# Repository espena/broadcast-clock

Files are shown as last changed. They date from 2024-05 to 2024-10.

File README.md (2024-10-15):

# Broadcast clock

**Digital precision studio/broadcast master clock with WiFi configuration, NTP client/server and GPS time sync.**

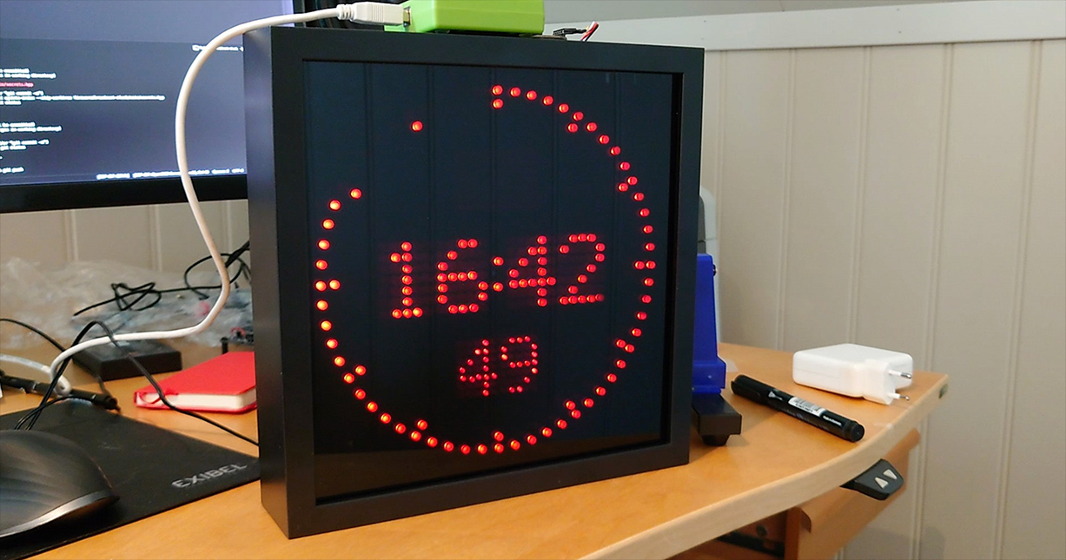
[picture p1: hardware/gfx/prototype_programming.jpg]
Home made broadcast clock Broadcast studio clock


## Details

You'll find a complete project description on [my personal home page](https://espenandersen.no/esp32-broadcast-clock/ "Broadcast clock with ESP32 and NTP/GPS time receiver").

The enclosure is an 25x25 cm [IKEA "Sannahed"](https://www.ikea.com/us/en/p/sannahed-frame-black-60459118/) photo frame, which is deep enough to encapsulate the circuitry. I replaced the provided plexi glass with a dark acrylic glass plate.

There are no traditional buttons to control the clock. Instead, it has a browser based web configurator. When powered on, the clock will expose a dedicated wifi network for 30 seconds. Connect to the network in order to access the clock's control panel.

The clock supports time synchronization over the web (NTP) or via a range of GNSS satellite systems (GPS/QZSS, GLONASS, BeiDou, Galileo). It acts as a highly accurate NTP time server for other clocks on your LAN.

LED brightness is auto-adjusted to ambient light conditions. This feature can be overridden in the control panel.

It also has a stopwatch and a countdown timer that is operated from the browser interface.

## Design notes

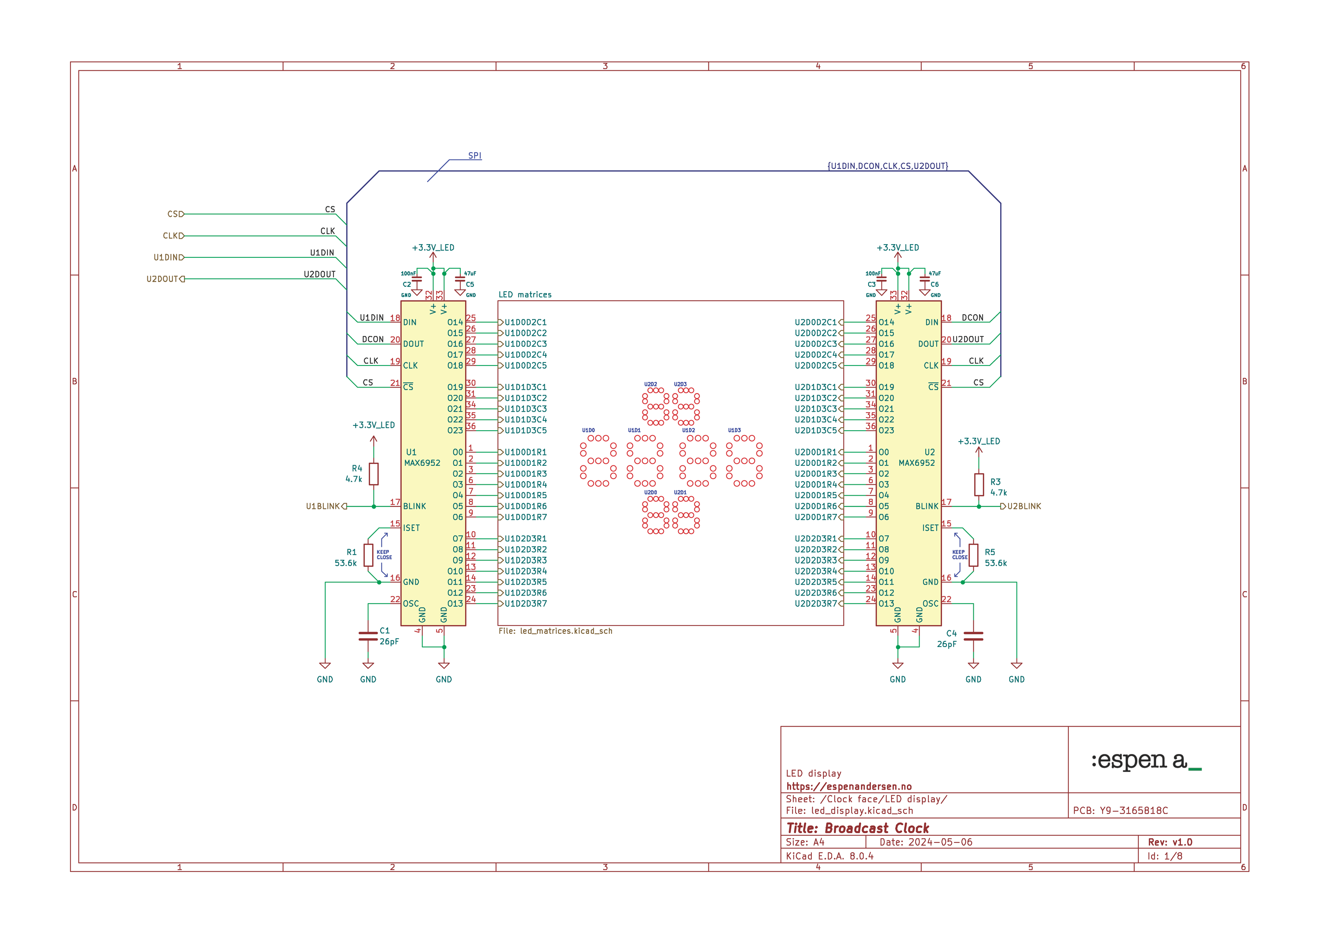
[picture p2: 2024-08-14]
drawings/schematics_png/schematics_Page_6.png

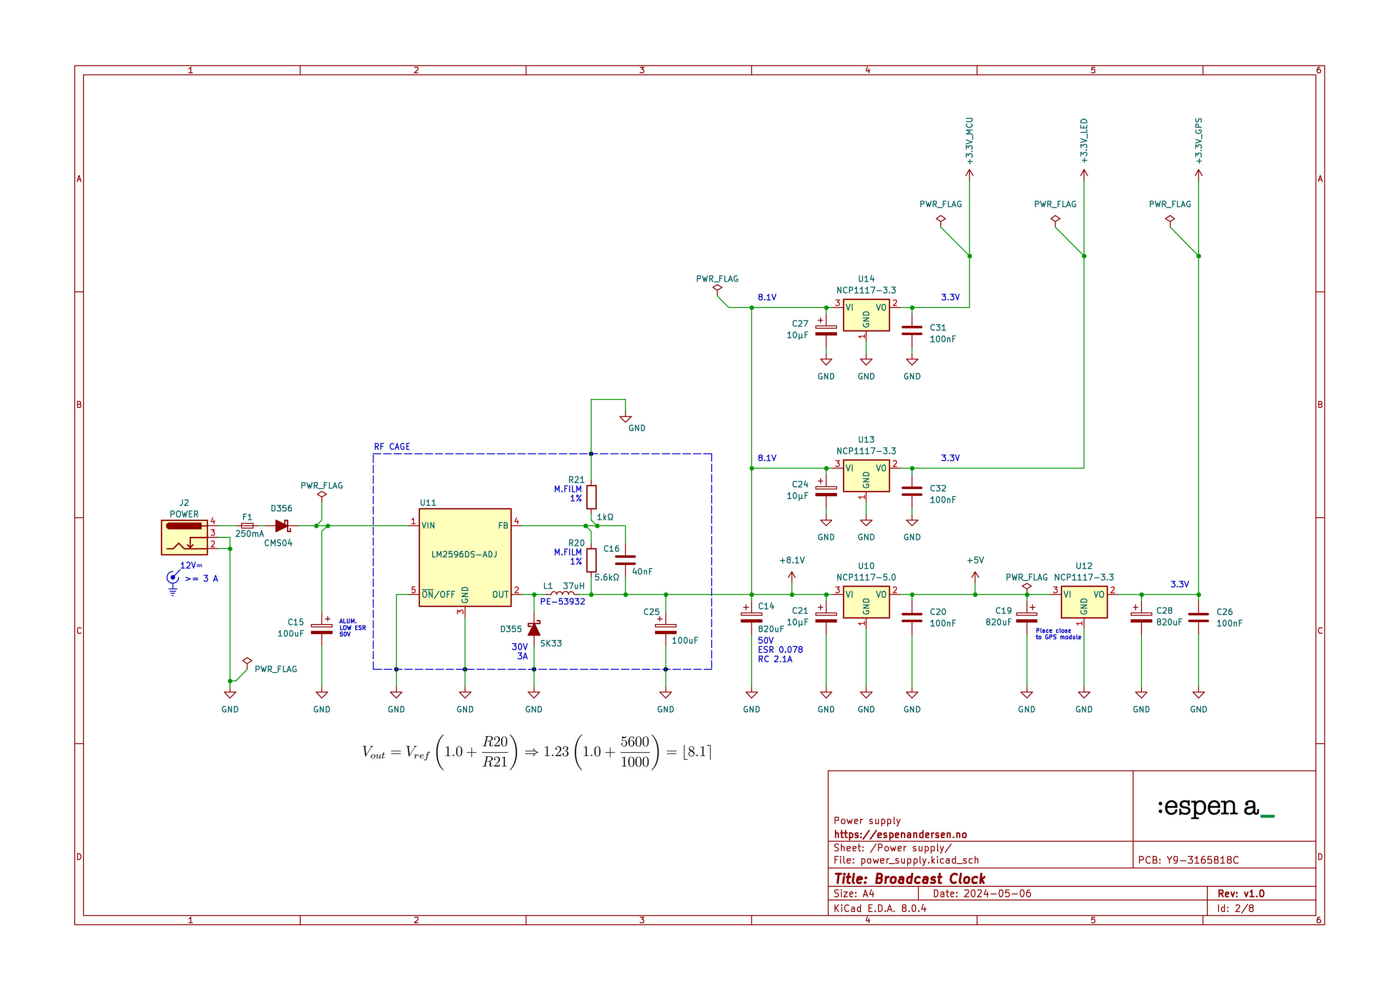
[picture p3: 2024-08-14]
drawings/schematics_png/schematics_Page_2.png

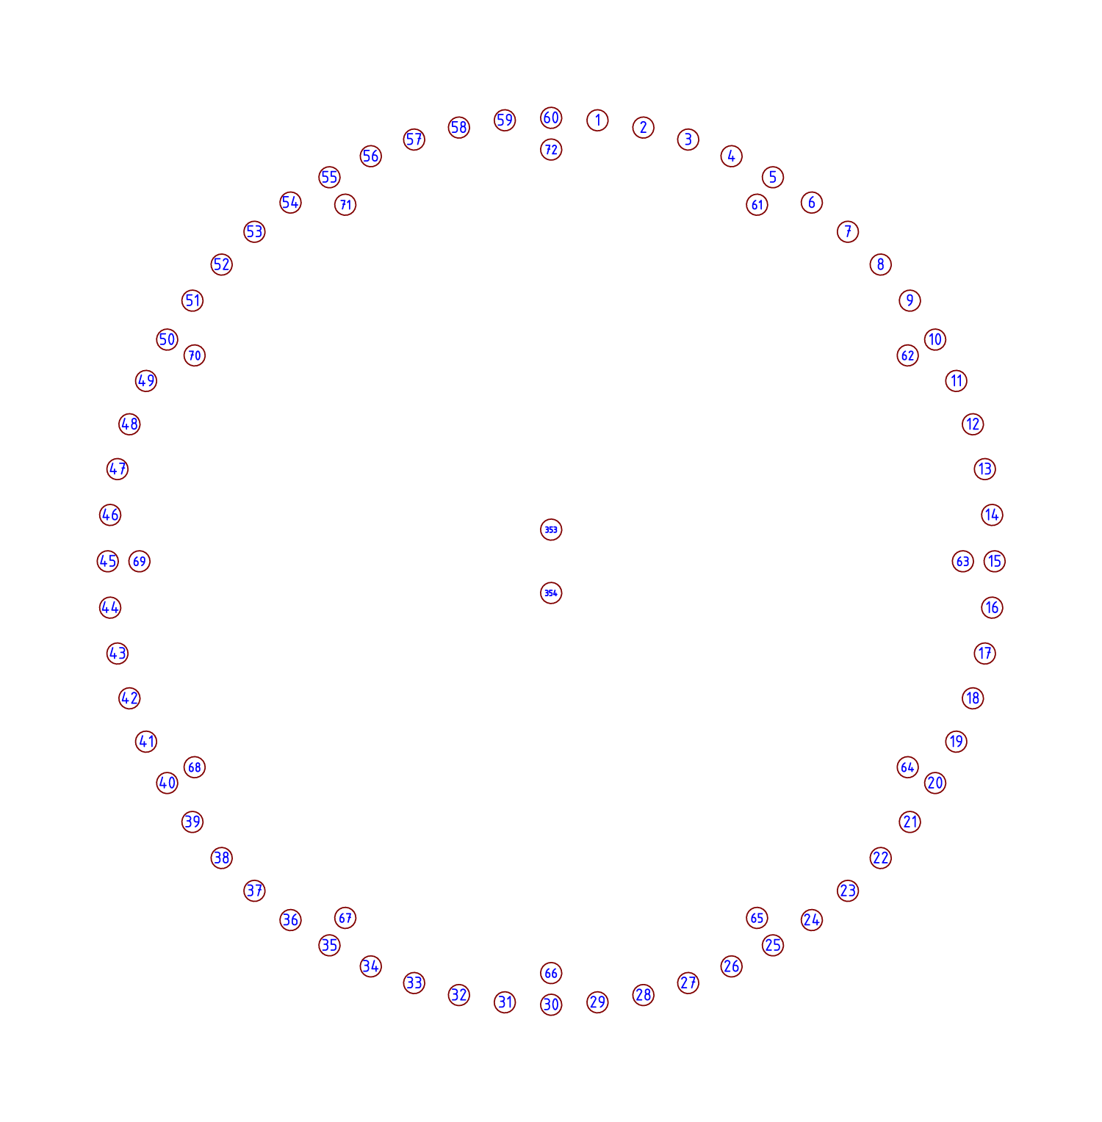
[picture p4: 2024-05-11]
hardware/gfx/dial.png

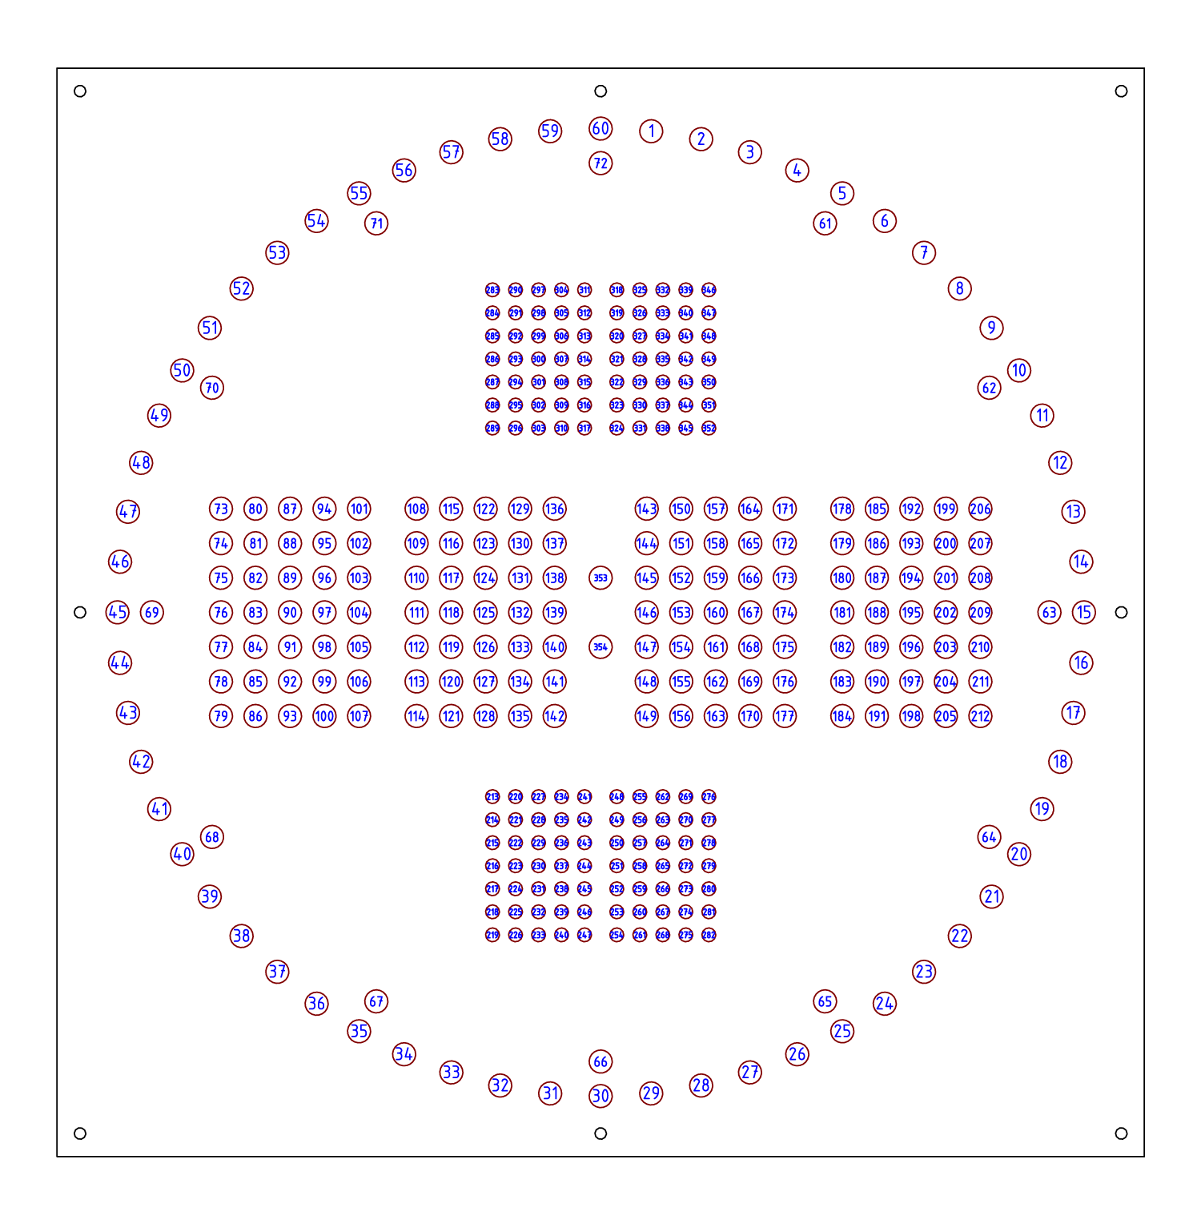
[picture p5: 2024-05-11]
hardware/gfx/face.png

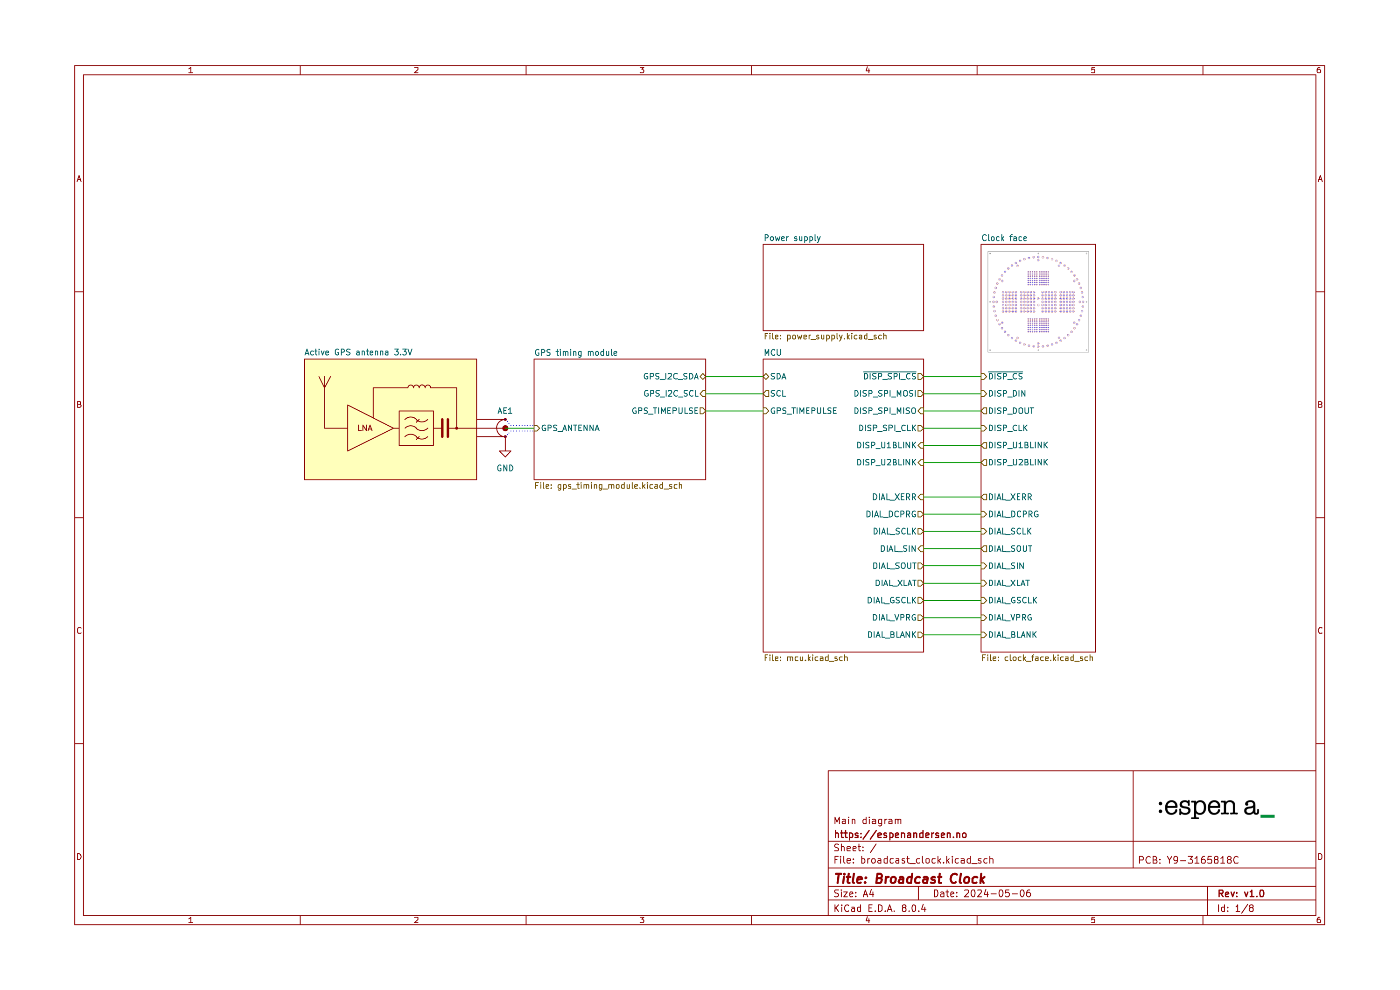
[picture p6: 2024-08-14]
drawings/schematics_png/schematics_Page_1.png

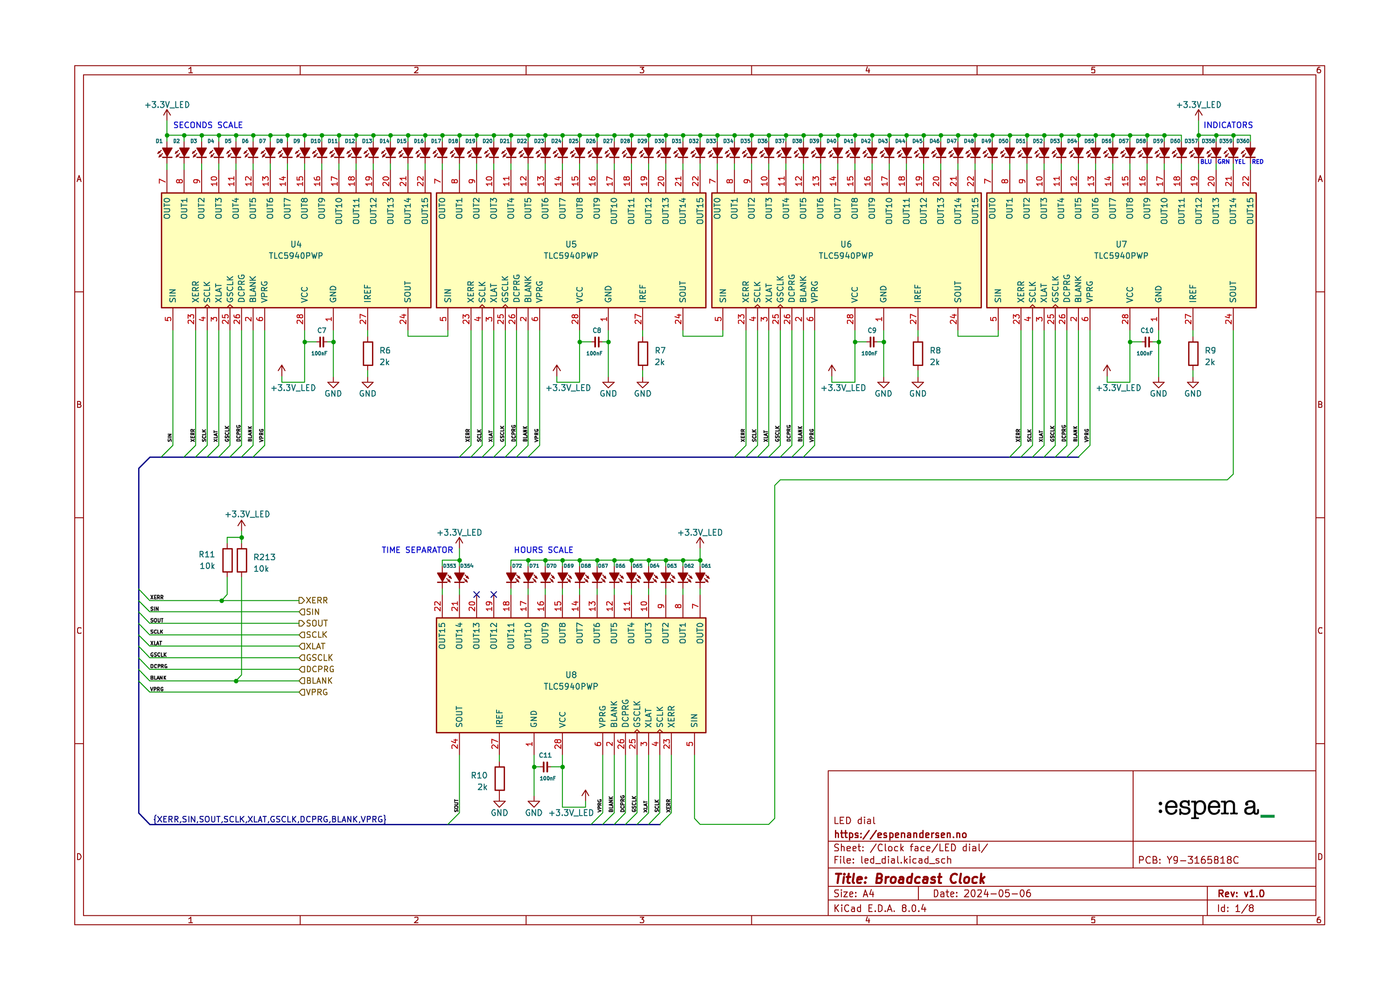
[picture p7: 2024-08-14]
drawings/schematics_png/schematics_Page_8.png

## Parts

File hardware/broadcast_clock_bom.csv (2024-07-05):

Reference | Value | Datasheet | Footprint | Qty | DNP
AE1 | Active GPS antenna 3.3V | ~ | Connector_Coaxial:SMA_Amphenol_132291-12_Vertical | 1
BT1 | CR 2032 | ~ | Battery:BatteryHolder_Keystone_1058_1x2032 | 1
BZ1 | Buzzer | ~ | Transducer_espena:TP094003_Transducer_9x9mm | 1
C1,C4 | 26pF | ~ | Capacitor_SMD:C_0805_2012Metric | 2
C2,C3,C7,C8,C9,C10,C11,C20,C22,C26,C31,C32 | 100nF | ~ | Capacitor_SMD:C_0805_2012Metric | 12
C5,C6,C13 | 47uF | ~ | Capacitor_SMD:C_0805_2012Metric | 3
C12 | 1uF | ~ | Capacitor_SMD:C_0805_2012Metric | 1
C14,C19,C28 | 820uF | ~ | Capacitor_SMD_espena:CP_Elec_18x16.5 | 3
C15,C25 | 100uF | ~ | Capacitor_SMD:CP_Elec_8x10 | 2
C16 | 40nF | ~ | Capacitor_SMD:C_0805_2012Metric | 1
C17 | 10nF | ~ | Capacitor_SMD:C_0805_2012Metric | 1
C18 | 47pF | ~ | Capacitor_SMD:C_0805_2012Metric | 1
C21,C24,C27 | 10µF | ~ | Capacitor_SMD:C_0805_2012Metric | 3
C23 | 10μF | ~ | Capacitor_SMD:C_0805_2012Metric | 1
D1,D2,D3,D4,D5,D6,D7,D8,D9,D10,D11,D12,D13,D14,D15,D16,D17,D18,D19,D20,D21,D22,D23,D24,D25,D26,D27,D28,D29,D30,D31,D32,D33,D34,D35,D36,D37,D38,D39,D40,D41,D42,D43,D44,D45,D46,D47,D48,D49,D50,D51,D52,D53,D54,D55,D56,D57,D58,D59,D60,D61,D62,D63,D64,D65,D66,D67,D68,D69,D70,D71,D72,D73,D74,D75,D76,D77,D78,D79,D80,D81,D82,D83,D84,D85,D86,D87,D88,D89,D90,D91,D92,D93,D94,D95,D96,D97,D98,D99,D100,D101,D102,D103,D104,D105,D106,D107,D108,D109,D110,D111,D112,D113,D114,D115,D116,D117,D118,D119,D120,D121,D122,D123,D124,D125,D126,D127,D128,D129,D130,D131,D132,D133,D134,D135,D136,D137,D138,D139,D140,D141,D142,D143,D144,D145,D146,D147,D148,D149,D150,D151,D152,D153,D154,D155,D156,D157,D158,D159,D160,D161,D162,D163,D164,D165,D166,D167,D168,D169,D170,D171,D172,D173,D174,D175,D176,D177,D178,D179,D180,D181,D182,D183,D184,D185,D186,D187,D188,D189,D190,D191,D192,D193,D194,D195,D196,D197,D198,D199,D200,D201,D202,D203,D204,D205,D206,D207,D208,D209,D210,D211,D212,D213,D214,D215,D216,D217,D218,D219,D220,D221,D222,D223,D224,D225,D226,D227,D228,D229,D230,D231,D232,D233,D234,D235,D236,D237,D238,D239,D240,D241,D242,D243,D244,D245,D246,D247,D248,D249,D250,D251,D252,D253,D254,D255,D256,D257,D258,D259,D260,D261,D262,D263,D264,D265,D266,D267,D268,D269,D270,D271,D272,D273,D274,D275,D276,D277,D278,D279,D280,D281,D282,D283,D284,D285,D286,D287,D288,D289,D290,D291,D292,D293,D294,D295,D296,D297,D298,D299,D300,D301,D302,D303,D304,D305,D306,D307,D308,D309,D310,D311,D312,D313,D314,D315,D316,D317,D318,D319,D320,D321,D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 | 620nm | ~ | -- mixed values -- | 355
D355 | SK33 | ~ | Diode_SMD:D_SMA | 1
D356 | CMS04 | ~ | Diode_SMD_mouser:SODFL4724X108N | 1
D357 | 470nm | ~ | LED_SMD:LED_0805_2012Metric | 1
D358 | 570nm | ~ | LED_SMD:LED_0805_2012Metric | 1
D359 | 590nm | ~ | LED_SMD:LED_0805_2012Metric | 1
F1 | 2A | ~ | Fuse_espena:FuseHolder_Keystone_3554 | 1
J1 | UART MCU | ~ | Connector_espena:Magnetic-Pogo-Female-MG0425FB_1x4_P2.54mm | 1
J2 | POWER | ~ | Connector_BarrelJack_espena:BarrelJack_DC044_Horizontal | 1
J3 | UART GPS | ~ | Connector_PinHeader_1.27mm:PinHeader_1x06_P1.27mm_Vertical | 1
L1 | 37uH | ~ | Inductor_SMD_espena:L_Pulse_LCI-44 | 1
L2 | 27nH | ~ | Inductor_SMD_espena:L_Coilcraft_0805CS | 1
R1,R5 | 53.6k | ~ | Resistor_SMD:R_0805_2012Metric | 2
R2,R3,R13 | 4.7k | ~ | Resistor_SMD:R_0805_2012Metric | 3
R4,R11 | R | ~ | Resistor_SMD:R_0805_2012Metric | 2
R6,R7,R8,R9,R10 | 2k | ~ | Resistor_SMD:R_0805_2012Metric | 5
R12 | 4,7k | ~ | Resistor_SMD:R_0805_2012Metric | 1
R14,R16,R22,R213 | 10k | ~ | Resistor_SMD:R_0805_2012Metric | 4
R15 | 10k | ~ | Resistor_SMD:R_0805_2012Metric | 1 | DNP
R17,R18 | 4k7 | ~ | Resistor_SMD:R_0805_2012Metric | 2 | DNP
R19 | 4k7 | ~ | Resistor_SMD:R_0805_2012Metric | 1
R20 | 5.6kΩ | ~ | Resistor_SMD:R_0805_2012Metric | 1
R21 | 1kΩ | ~ | Resistor_SMD:R_0805_2012Metric | 1
R24 | 10Ω | ~ | Resistor_SMD:R_0805_2012Metric | 1
SW1 | BOOT | ~ | Button_Switch_SMD_espena:SW_SPST_TL3301_6x6mm_H4.3mm | 1
SW2 | RESET | ~ | Button_Switch_SMD_espena:SW_SPST_TL3301_6x6mm_H4.3mm | 1
U1,U2 | MAX6952 | https://www.analog.com/MAX6952/datasheet | Package_SO_espena:SSOP-36_7.5x12.5mm_P0.65mm | 2
U3 | ESP32-WROVER-E | https://www.espressif.com/sites/default/files/documentation/esp32-wrover-b_datasheet_en.pdf | RF_Module_espena:ESP32-WROVER-B | 1
U4,U5,U6,U7,U8 | TLC5940PWP | http://www.ti.com/lit/ds/symlink/tlc5940.pdf | Package_SO:HTSSOP-28-1EP_4.4x9.7mm_P0.65mm_EP3.4x9.5mm_Mask2.4x6.17mm_ThermalVias | 5
U9 | LEA-M8T | https://content.u-blox.com/sites/default/files/documents/NEO-LEA-M8T-FW3_DataSheet_UBX-15025193.pdf | RF_GPS_espena:ublox_LEA | 1
U10 | NCP1117-5.0 | http://www.onsemi.com/pub_link/Collateral/NCP1117-D.PDF | Package_TO_SOT_SMD:SOT-223-3_TabPin2 | 1
U11 | LM2596DS-ADJ | http://www.ti.com/lit/ds/symlink/lm2596.pdf | Regulator_SMD_mouser:NCP5663DSADJR4G | 1
U12,U13,U14 | NCP1117-3.3 | http://www.onsemi.com/pub_link/Collateral/NCP1117-D.PDF | Package_TO_SOT_SMD:SOT-223-3_TabPin2 | 3
U15 | VEML7700 | https://www.vishay.com/docs/84286/veml7700.pdf | Sensor_espena:VEML7700 | 1

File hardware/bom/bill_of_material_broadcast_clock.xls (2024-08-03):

BROADCAST CLOCK
Mouser No | Mfr. No | Manufacturer | Description | RoHS | Order Qty. | Price (NOK) | Ext.: (NOK)
700-MAX6952EAX | MAX6952EAX+ | Analog Devices Inc. | LED Display Drivers 4-Wire Interfaced, 2.7V to 5.5V, 4-Digit | RoHS Compliant | 2 | kr 399.98 | kr 799.96
595-TLC5940PWPR | TLC5940PWPR | Texas Instruments | LED Lighting Drivers 4096 Step Grayscale LED Driver | RoHS Compliant | 5 | kr 33.26 | kr 166.30
863-LM2596DSADJR4G | LM2596DSADJR4G | onsemi | Switching Voltage Regulators 3A BUCK SWCH 150KHZ | RoHS Compliant By Exemption | 1 | kr 28.99 | kr 28.99
833-SK33A-LTP | SK33A-LTP | Micro Commercial Components (MCC) | Schottky Diodes & Rectifiers DIODE SCHOTTKY 30V 3A DO214AC | RoHS Compliant By Exemption | 1 | kr 4.62 | kr 4.62
673-PE-53932SNLT | PE-53932SNLT | Pulse | Common Mode Chokes / Filters SMT COMMON MODE INDUCTOR | RoHS Compliant | 1 | kr 33.15 | kr 33.15
647-UCZ1H821MNS1MS | UCZ1H821MNS1MS | Nichicon | Aluminium Electrolytic Capacitors - SMD 50V 820uf 20% SMD, high vibration | RoHS Compliant | 3 | kr 33.84 | kr 101.52
647-UWT1H101MNL1S | UWT1H101MNL1GS | Nichicon | Aluminium Electrolytic Capacitors - SMD 50volts 100uF AEC-Q200 | RoHS Compliant | 1 | kr 5.15 | kr 5.15
757-CMS04TE12L,Q,M | CMS04(TE12L,Q,M) | Toshiba | Schottky Diodes & Rectifiers Diode Schottky 30V 5A | RoHS Compliant | 1 | kr 9.24 | kr 9.24
377-LEA-M8T-1 | LEA-M8T-1 | u-blox | GNSS / GPS Modules u-blox M8 GNSS module Timing LCC, 17x22.4mm, 250 pcs/reel | RoHS Compliant | 1 | kr 1031.18 | kr 1031.18
530-MRT250AMMO | MRT250AMMO | Bel | Fuses with Leads - Through Hole 250mA 250V | RoHS Compliant | 1 | kr 4.84 | kr 4.84
652-CR0805FX-5601ELF | CR0805-FX-5601ELF | Bourns | Thick Film Resistors - SMD 5.6K 1% | RoHS Compliant By Exemption | 1 | kr 1.07 | kr 1.07
652-CR0805FX-1001ELF | CR0805-FX-1001ELF | Bourns | Thick Film Resistors - SMD 1K 1% | RoHS Compliant By Exemption | 1 | kr 1.07 | kr 1.07
80-C0805C393F5J | C0805C393F5JACTU | KEMET | Multilayer Ceramic Capacitors MLCC - SMD/SMT 50V .039uF U2J 0805 1% | RoHS Compliant | 1 | kr 13.40 | kr 13.40
80-C0805X106J8RAUTO | C0805X106J8RACAUTO | KEMET | Multilayer Ceramic Capacitors MLCC - SMD/SMT 10 Vo 10 uF 0805 X7R 5 % AECQ200 | RoHS Compliant | 4 | kr 10.31 | kr 41.24
80-C0805C104K8RAUTO | C0805C104K8RACAUTO | KEMET | Multilayer Ceramic Capacitors MLCC - SMD/SMT 10Vo 0.1uF X7R 0805 10% AEC-Q200 | RoHS Compliant | 12 | kr 0.87 | kr 10.39
863-NCP1117IST50T3G | NCP1117IST50T3G | onsemi | LDO Voltage Regulators LDO Regulator, 1 A, Fixed and Adjustable, Positive Vout: 5.0 V | RoHS Compliant | 1 | kr 6.44 | kr 6.44
863-NCP1117ST33T3G | NCP1117ST33T3G | onsemi | LDO Voltage Regulators 3.3V 1A Positive | RoHS Compliant | 3 | kr 7.30 | kr 21.90
78-VEML7700-TR | VEML7700-TR | Vishay | Ambient Light Sensors Opr 2.5-3.6V 0.005lx Side View 16bit I2C | RoHS Compliant | 1 | kr 18.83 | kr 18.83
652-CR0805FX-10R0ELF | CR0805-FX-10R0ELF | Bourns | Thick Film Resistors - SMD 10ohm 1% | RoHS Compliant By Exemption | 2 | kr 1.07 | kr 2.14
179-TS046685BK260SMT | TS04-66-85-BK-260-SMT | CUI Devices | Tactile Switches 6 x 6 mm, 8.5 mm Act Height, 260 gf, Black, Surface Mount, SPST, | RoHS Compliant | 2 | kr 1.93 | kr 3.86
652-CR0805FX-1002ELF | CR0805-FX-1002ELF | Bourns | Thick Film Resistors - SMD 10K 1% | RoHS Compliant By Exemption | 6 | kr 1.07 | kr 6.42
652-CR0805-JW-472ELF | CR0805-JW-472ELF | Bourns | Thick Film Resistors - SMD 4.7KOHM 1/8WATT 5% | RoHS Compliant By Exemption | 4 | kr 1.07 | kr 4.28
187-CL21X476MRYNNWE | CL21X476MRYNNWE | Samsung Electro-Mechanics | Multilayer Ceramic Capacitors MLCC - SMD/SMT 47uF X6S +/-20% 4v 0 0805 | RoHS Compliant | 3 | kr 3.12 | kr 9.36
187-CL21B105KOFNNNE | CL21B105KOFNNNE | Samsung Electro-Mechanics | Multilayer Ceramic Capacitors MLCC - SMD/SMT SAMSUNG | RoHS Compliant | 1 | kr 1.07 | kr 1.07
497-TP094003-1 | TP094003-1 | DB Unlimited | Speakers & Transducers Piezo Transducer | RoHS Compliant | 1 | kr 7.30 | kr 7.30
855-M50-3530642 | M50-3530642 | Harwin | Headers & Wire Housings 6 WAY SIL VERT PC TAIL P/HDR | RoHS Compliant | 1 | kr 3.12 | kr 3.12
534-1058 | 1058 | Keystone Electronics | Coin Cell Battery Holders 2032 COIN CELL HLDER SMT 1.118" | RoHS Compliant | 1 | kr 13.17 | kr 13.17
581-08052U470FAT2A | 08052U470FAT2A | KYOCERA AVX | Multilayer Ceramic Capacitors MLCC - SMD/SMT KGQ21HCG2D470FT NEW GLOBAL PN 200V 47pF A 581-KGQ21HCG2D470FT | RoHS Compliant | 1 | kr 5.05 | kr 5.05
581-0805YA103FAT2A | 0805YA103FAT2A | KYOCERA AVX | Multilayer Ceramic Capacitors MLCC - SMD/SMT KGM21ACG1C103FU NEW GLOBAL PN 16V 0.01uF A 581-KGM21ACG1C103FU | RoHS Compliant | 1 | kr 10.21 | kr 10.21
652-CR0805FX-5362ELF | CR0805-FX-5362ELF | Bourns | Thick Film Resistors - SMD 53.6K 1% | RoHS Compliant By Exemption | 2 | kr 1.07 | kr 2.14
77-VJ0805A270FXXPBC | VJ0805A270FXXPW1BC | Vishay | Multilayer Ceramic Capacitors MLCC - SMD/SMT 0805 27pF 25volts C0G 1% | RoHS Compliant | 2 | kr 3.55 | kr 7.10
859-LTL-307E | LTL-307E | Lite-On | Standard LEDs - Through Hole Red Diffused | RoHS Compliant | 214 | kr 0.94 | kr 200.30
859-LTL-1CHE | LTL-1CHE | Lite-On | Standard LEDs - Through Hole Red Diffused | RoHS Compliant | 140 | kr 0.85 | kr 119.70
652-CR0805FX-1003ELF | CR0805-FX-1003ELF | Bourns | Thick Film Resistors - SMD 100K 1% | RoHS Compliant By Exemption | 1 | kr 1.07 | kr 1.07
652-CR0805FX-2001ELF | CR0805-FX-2001ELF | Bourns | Thick Film Resistors - SMD 2K 1% | RoHS Compliant By Exemption | 5 | kr 1.07 | kr 5.35
710-150080YS75000 | 150080YS75000 | Wurth Elektronik | Standard LEDs - SMD WL-SMCW SMDMono TpVw Waterclr 0805 Yellow | RoHS Compliant | 1 | kr 2.04 | kr 2.04
710-150080VS75000 | 150080VS75000 | Wurth Elektronik | Standard LEDs - SMD WL-SMCW SMDMono TpVw Waterclr 0805 BrtGrn | RoHS Compliant | 1 | kr 2.04 | kr 2.04
710-150080RS75000 | 150080RS75000 | Wurth Elektronik | Standard LEDs - SMD WL-SMCW SMDMono TpVw Waterclr 0805 Red | RoHS Compliant | 1 | kr 2.04 | kr 2.04
710-150080BS75000 | 150080BS75000 | Wurth Elektronik | Standard LEDs - SMD WL-SMCW SMDMono TpVw Waterclr 0805 Blue | RoHS Compliant | 1 | kr 2.04 | kr 2.04
523-132291-12 | 132291-12 | Amphenol | RF Connectors / Coaxial Connectors STRT BH PC MT JK .105 LEGS | RoHS Compliant By Exemption | 1 | kr 93.79 | kr 93.79
356-ESP32WRVE22864PC | ESP32-WROVER-E-N16R8 | Espressif | Multiprotocol Modules SMD Module ESP32-WROVER-E, ESP32-D0WD-V3, 3.3V 64Mbit PSRAM, 16 MB SPI flash, PCB Antenna | RoHS Compliant | 1 | kr 36.38 | kr 36.38
 |  | DC Barrel plug |  |  | 1 | kr 1.00 | kr 1.00
 |  | Enclosure | IKEA "Sannahed" |  | 1 | kr 69.00 | kr 55.00
 |  | PCB | JLCPCB |  | 1 | kr 440.00 | kr 280.00
 |  | Acrylic front glass |  |  | 1 | kr 150.00 | kr 150.00
 |  | Back plate | Tronrud Engineering |  | 1 | kr 200.00 | kr 200.00
 |  | Munting material | Standoffs, nuts, screws |  |  | kr 50.00 | kr 30.00
 |  | Grand total |  |  |  |  | kr 3555.26

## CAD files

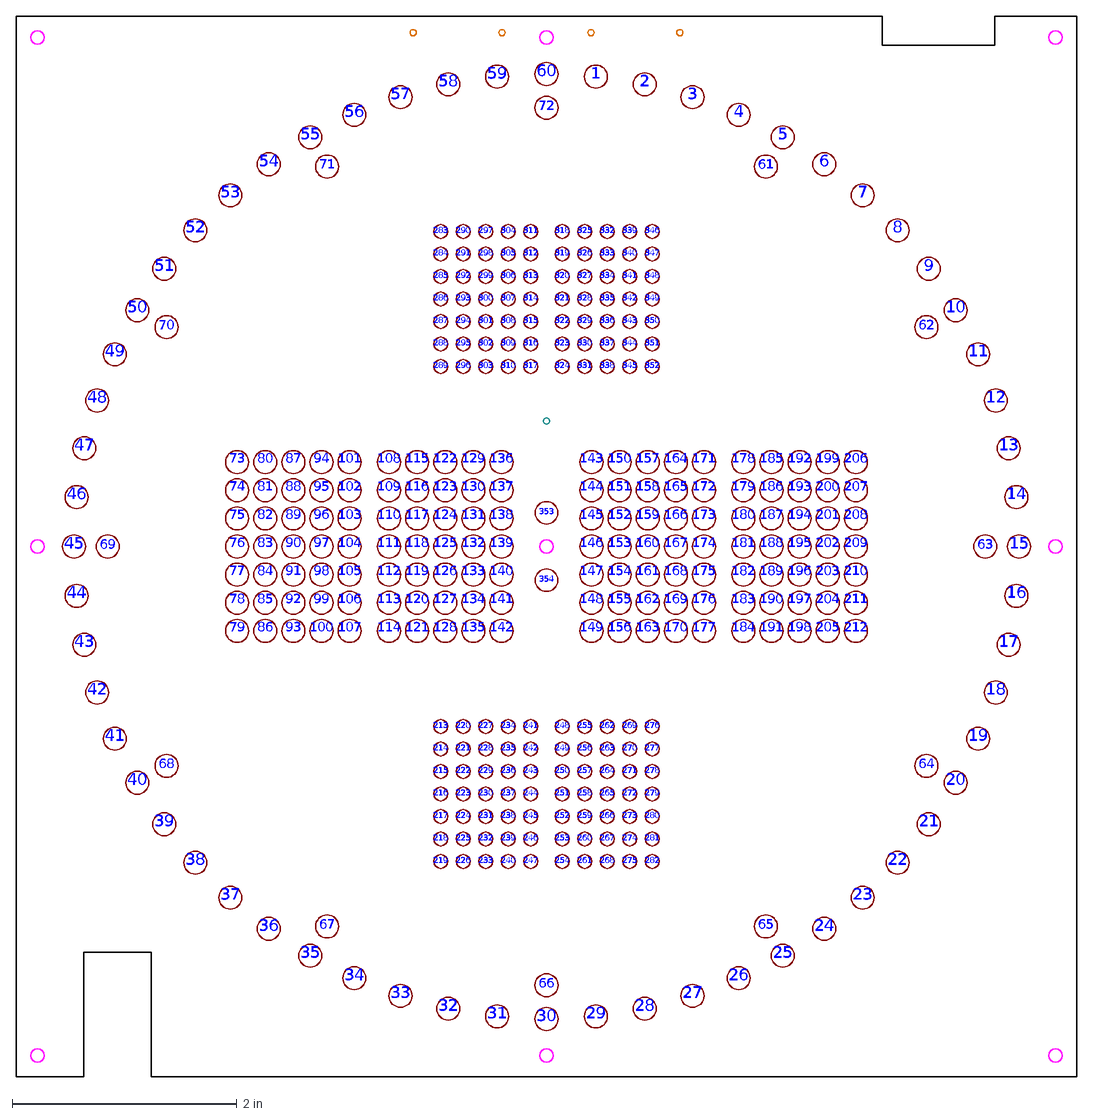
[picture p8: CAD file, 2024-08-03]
drawings/clock_panels.dxf
1
2
3
4
5
6
7
8
9
10
11
12
13
14
15
16
17
18
19
20
21
22
23
24
25
26
27
28
29
30
31
32
33
34
35
36
37
38
39
40
41
42
43
44
45
46
47
48
49
50
51
52
53
54
55
56
57
58
59
60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

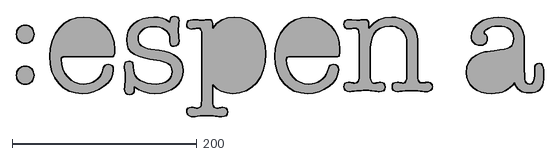
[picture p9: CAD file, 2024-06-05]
hardware/gfx/logo.dxf
571.4 x 108.8

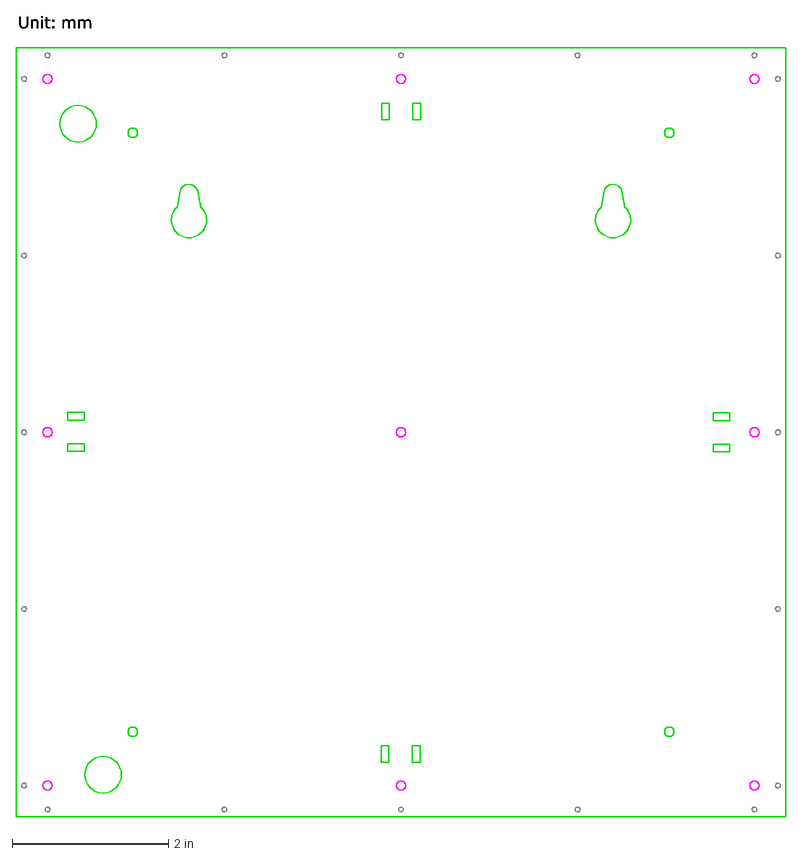
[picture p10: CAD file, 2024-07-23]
drawings/back_plate.dxf
Unit: mm

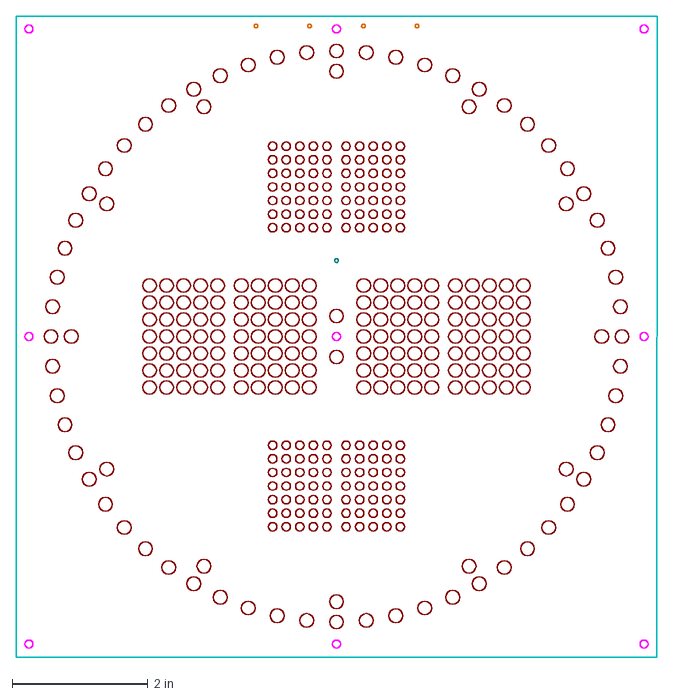
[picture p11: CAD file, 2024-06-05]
drawings/front_panel.dxf
9.43 x 9.43 in

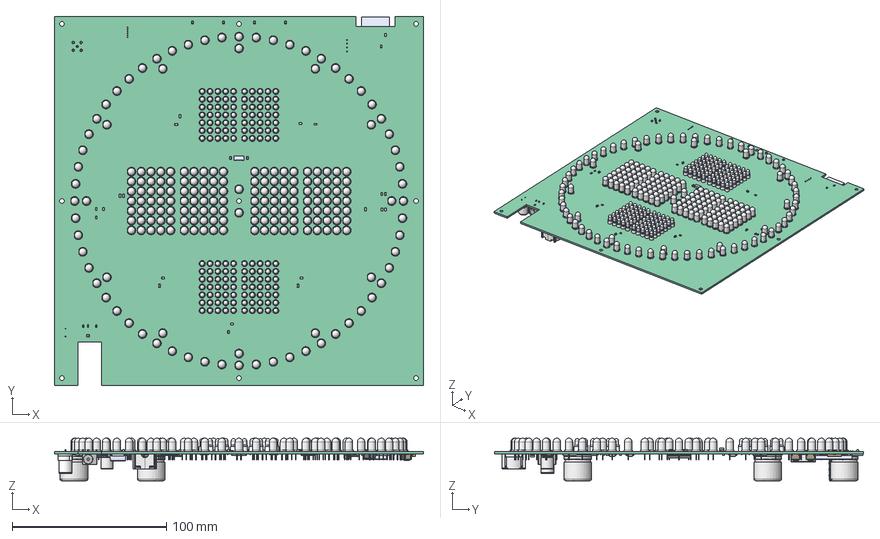
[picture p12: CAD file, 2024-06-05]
drawings/printed_circuit_board.FCStd
239.5 x 239.5 x 27.8 mm
Pcb_7181
${REFERENCE}_LED_D3.0mm_null x 140
${REFERENCE}_Body_null[2] x 140
${REFERENCE}_LED_D5.0mm_null x 214
${REFERENCE}_R_0805_2012Metric_null x 24
${REFERENCE}_C_0805_2012Metric_null x 25
${REFERENCE}_LED_0805_2012Metric_null x 4
${REFERENCE}_VEML7700-TR_null
${REFERENCE}_HTSSOP_28_1EP_44x97mm_P065mm_null x 5
${REFERENCE}_SOT_223_null x 4
${REFERENCE}_Keystone_1058_1x2032_null
${REFERENCE}_CP_Elec_18x175_null x 3
${REFERENCE}_SW_SPST_TL3301_6x6mm_H4.3mm_null x 2
${REFERENCE}_SMA_Amphenol_132291-12_Vertical_null
${REFERENCE}_ESP32-WROVER-B_null
${REFERENCE}_DC044_connector_5.5x2.1mm_null
${REFERENCE}_D_SMA_null
${REFERENCE}_Inductor_Coilcraft_0805CS_null
${REFERENCE}_PinHeader_1x06_P127mm_Vertical_null
${REFERENCE}_Fuse_MXT250_With_Socket_null
${REFERENCE}_Fuse_MXT250_null[2]
${REFERENCE}_PE5393NSL_inductor_null
${REFERENCE}_MAX6952EAX+_null x 2
${REFERENCE}_PogoFemale_null
${REFERENCE}_LM2596DSADJR4G_null
${REFERENCE}_Ublox_LEA_M8T_null
${REFERENCE}_CP_Elec_8x10_null
${REFERENCE}_TP094003_Transducer_9x9mm_null
${REFERENCE}_CMS04_null

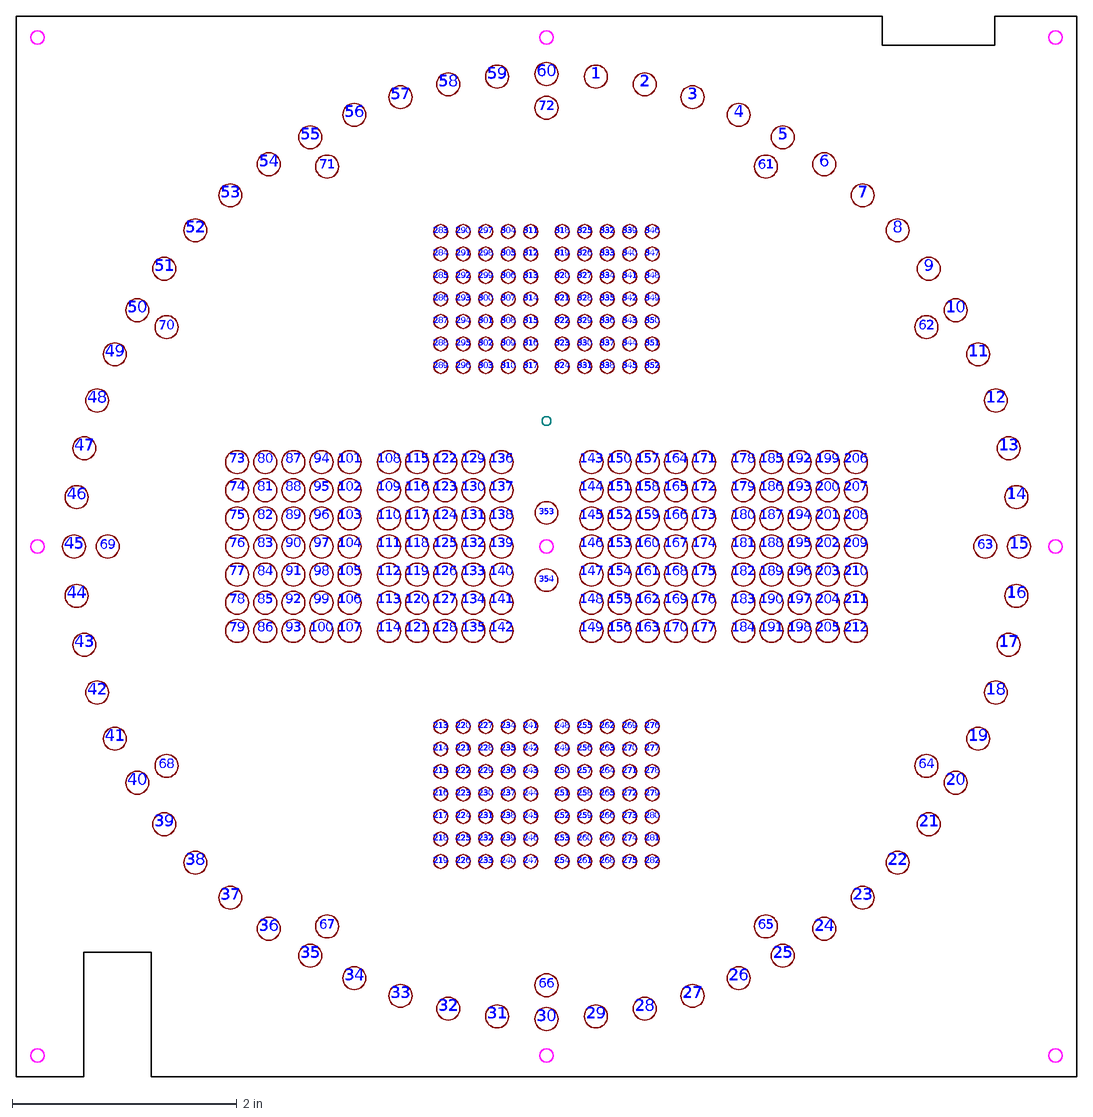
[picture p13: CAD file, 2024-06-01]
drawings/user_1.dxf
1
2
3
4
5
6
7
8
9
10
11
12
13
14
15
16
17
18
19
20
21
22
23
24
25
26
27
28
29
30
31
32
33
34
35
36
37
38
39
40
41
42
43
44
45
46
47
48
49
50
51
52
53
54
55
56
57
58
59
60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

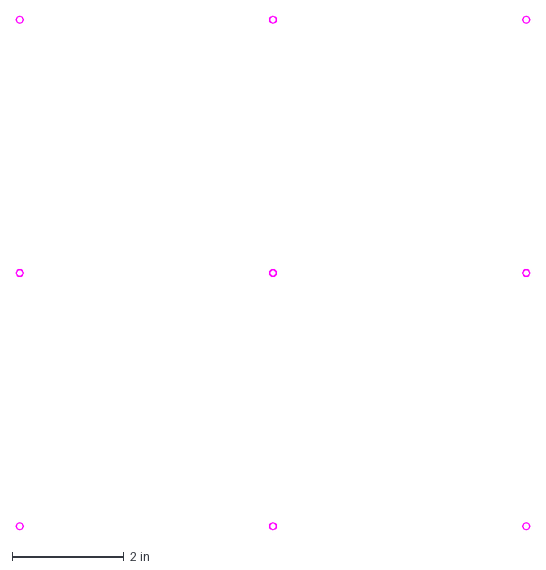
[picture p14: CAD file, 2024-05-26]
drawings/mounting_holes.dxf
9.17 x 9.17 in

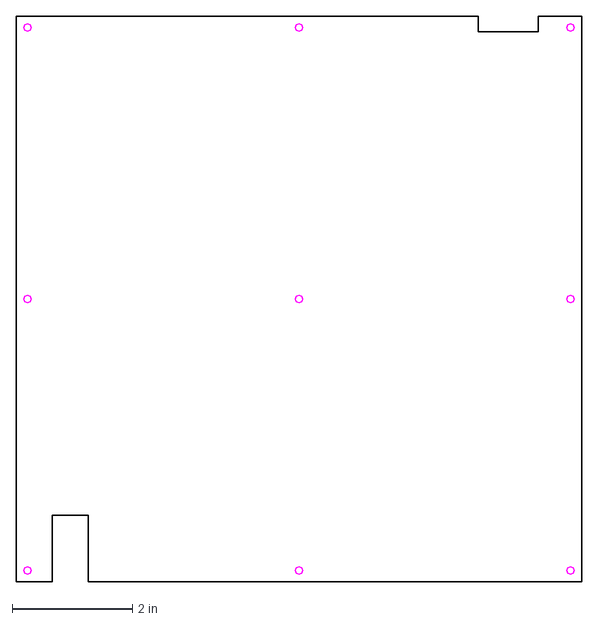
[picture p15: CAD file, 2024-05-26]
drawings/edge_cuts.dxf
9.43 x 9.43 in

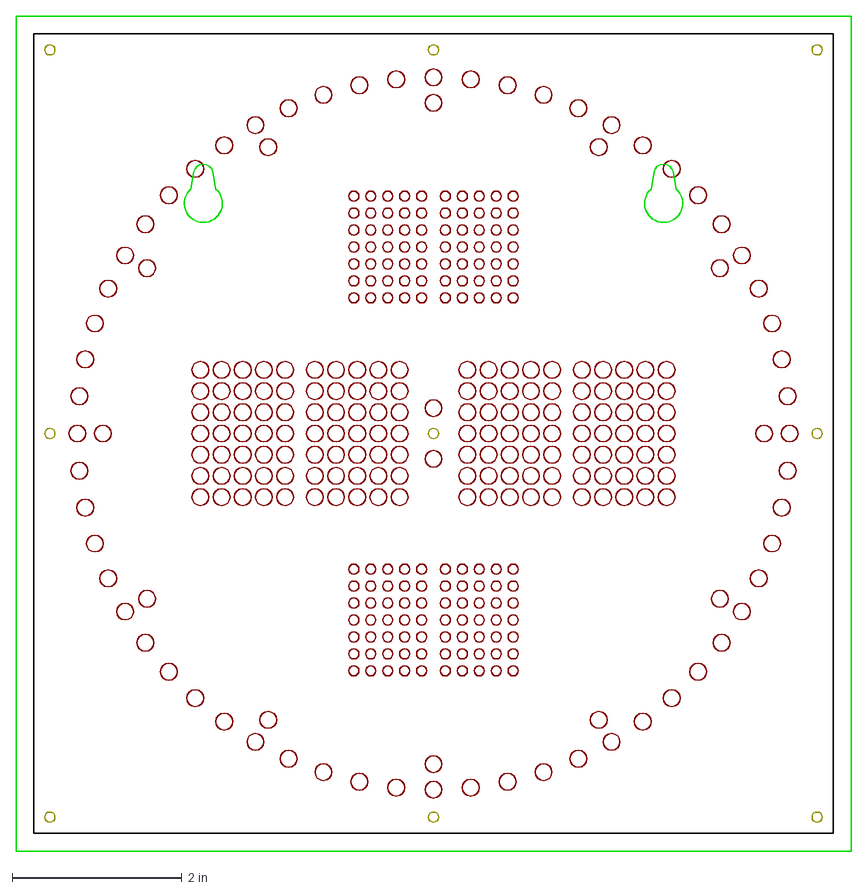
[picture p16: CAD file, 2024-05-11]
drawings/clock_face.backup.dxf
9.85 x 9.85 in

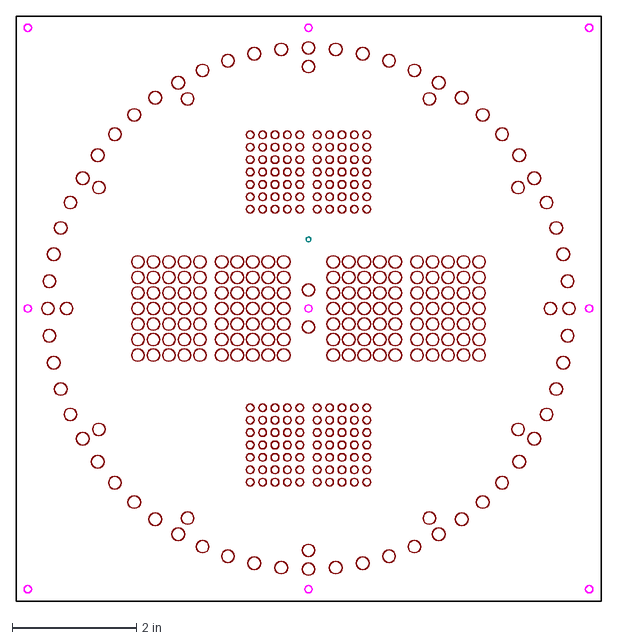
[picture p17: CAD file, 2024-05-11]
drawings/front_panel_template.dxf
9.43 x 9.43 in

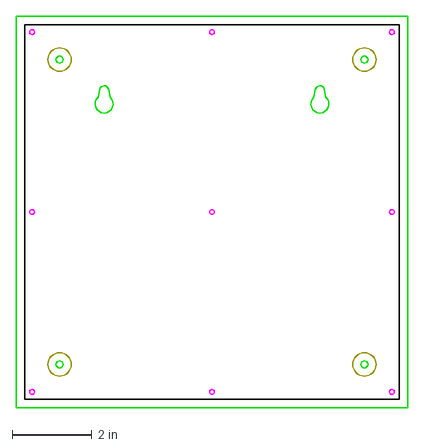
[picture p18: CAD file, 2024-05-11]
drawings/back_panel_template.dxf
9.85 x 9.85 in

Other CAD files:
drawings/clock_face.dxf

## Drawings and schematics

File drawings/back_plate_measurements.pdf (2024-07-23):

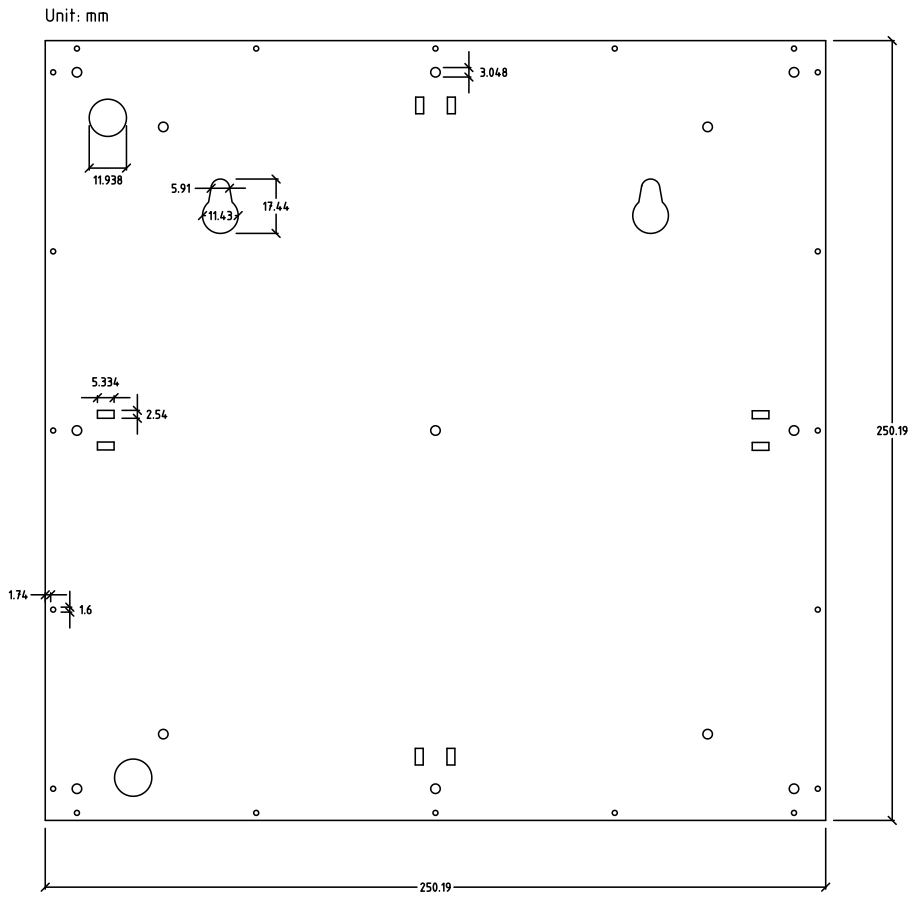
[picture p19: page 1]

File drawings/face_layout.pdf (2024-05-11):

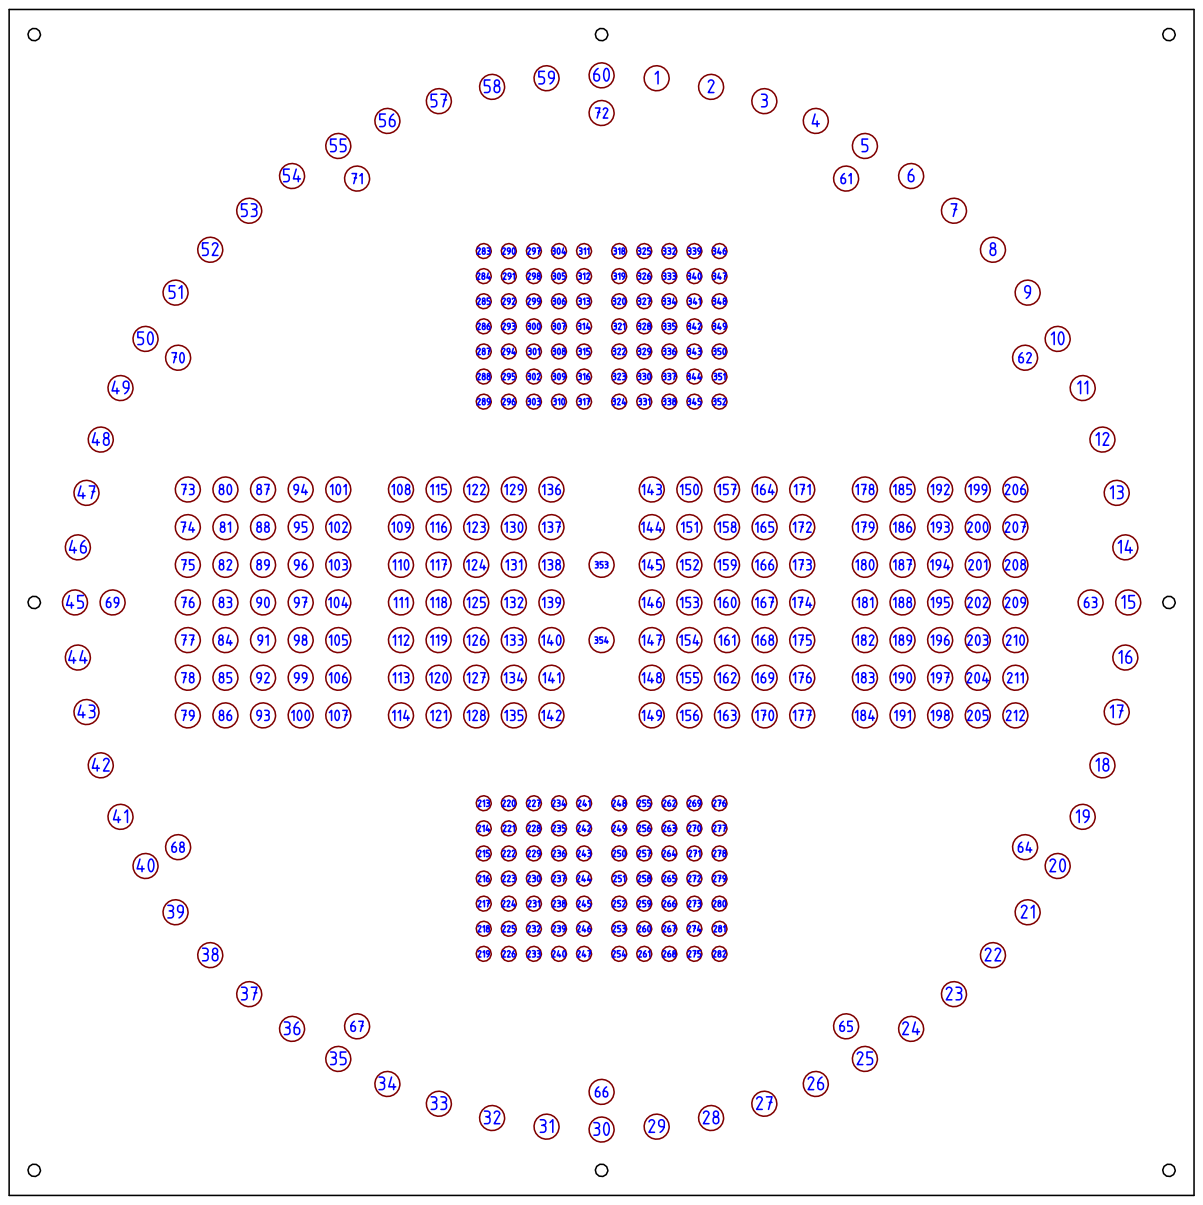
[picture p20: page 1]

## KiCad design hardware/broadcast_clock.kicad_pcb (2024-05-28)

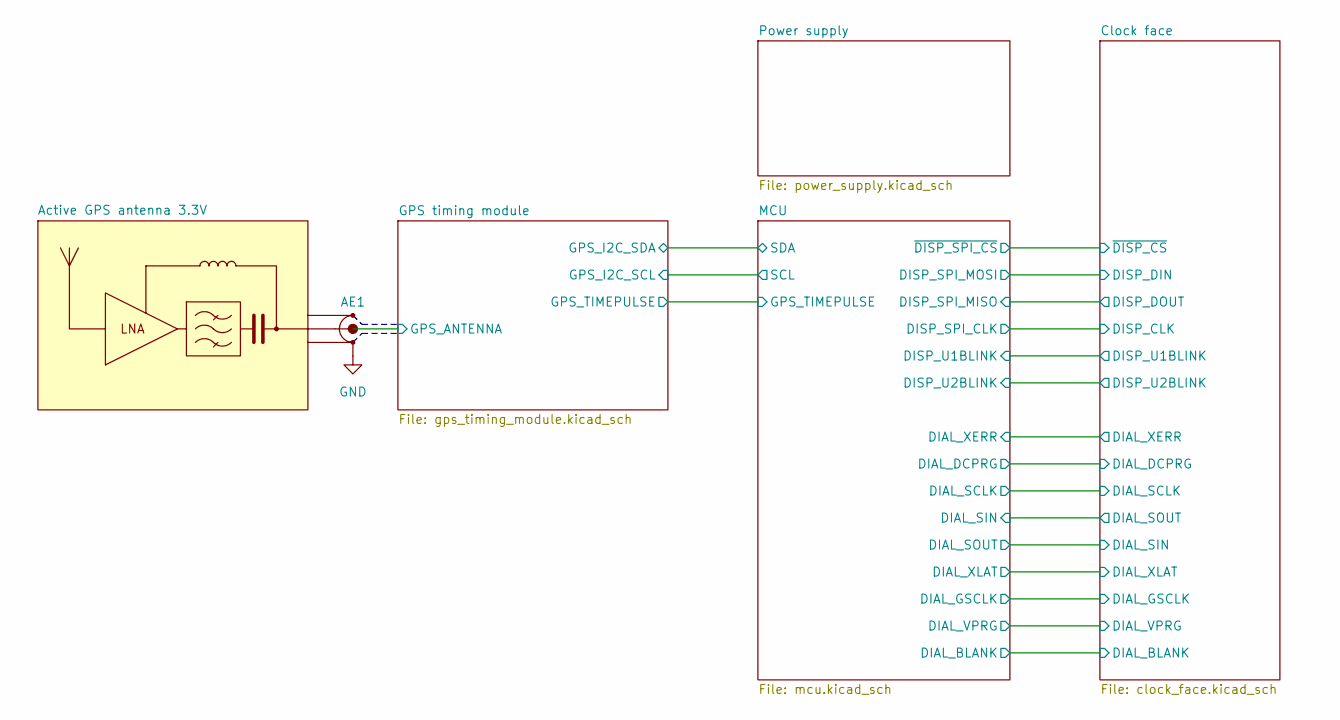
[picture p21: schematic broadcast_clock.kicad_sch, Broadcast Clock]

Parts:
AE1: Active GPS antenna 3.3V; SMA_Amphenol_132291-12_Vertical

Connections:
/GPS timing module/GPS_ANTENNA: AE1.1 (ANT); also elsewhere on the board
GND: AE1.2 (SHIELD); also elsewhere on the board

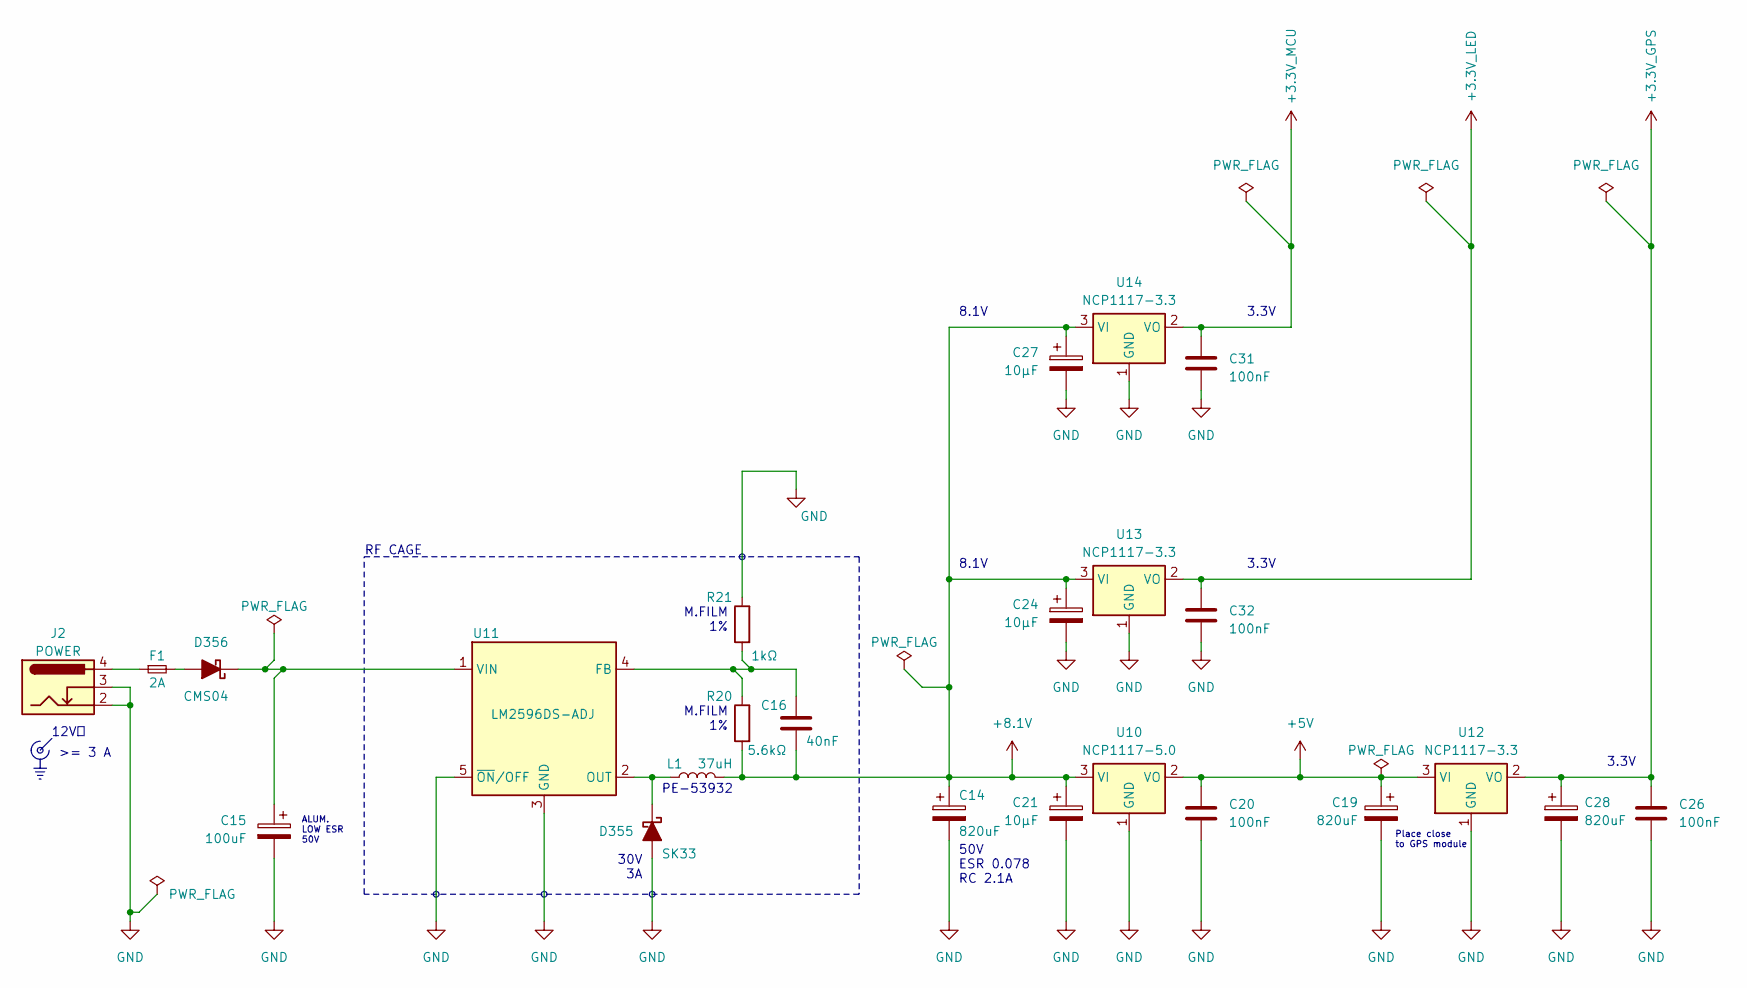
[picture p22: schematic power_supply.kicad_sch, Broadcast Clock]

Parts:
C14, C19, C28: 820uF; CP_Elec_18x16.5
C15: 100uF; CP_Elec_8x10
C16: 40nF; C_0805_2012Metric
C20, C26, C31, C32: 100nF; C_0805_2012Metric
C21, C24, C27: 10µF; C_0805_2012Metric
D355: SK33; D_SMA
D356: CMS04; SODFL4724X108N
F1: 2A; FuseHolder_Keystone_3554
J2: POWER; BarrelJack_DC044_Horizontal
L1: 37uH; L_Pulse_LCI-44
R20: 5.6kΩ; R_0805_2012Metric
R21: 1kΩ; R_0805_2012Metric
U10: NCP1117-5.0; SOT-223-3_TabPin2
U11: LM2596DS-ADJ; NCP5663DSADJR4G
U12, U13, U14: NCP1117-3.3; SOT-223-3_TabPin2

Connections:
+3.3V_GPS: C26.1, C28.1, U12.2 (VO); also elsewhere on the board
+3.3V_LED: C32.1, U13.2 (VO); also elsewhere on the board
+3.3V_MCU: C31.1, U14.2 (VO); also elsewhere on the board
+5V: C19.1, C20.1, U10.2 (VO), U12.3 (VI)
+8.1V: C14.1, C16.2, C21.1, C24.1, C27.1, L1.2, R20.2, U10.3 (VI), U13.3 (VI), U14.3 (VI)
GND: C14.2, C15.2, C19.2, C20.2, C21.2, C24.2, C26.2, C27.2, C28.2, C31.2, C32.2, D355.2 (A), J2.2, J2.3, R21.1, U10.1 (GND), U11.3 (GND), U11.5 (~ON/OFF), U12.1 (GND), U13.1 (GND), U14.1 (GND); also elsewhere on the board
unnamed: D355.1 (K), L1.1, U11.2 (OUT)
unnamed: D356.2 (A), F1.2
unnamed: C15.1, D356.1 (K), U11.1 (VIN)
unnamed: F1.1, J2.4
unnamed: C16.1, R20.1, R21.2, U11.4 (FB)

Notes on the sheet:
M.FILM 1%
3.3V
ALUM. LOW ESR 50V
PE-53932
Place close to GPS module
RF CAGE
12V⎓
30V 3A
8.1V
>= 3 A
50V ESR 0.078 RC 2.1A

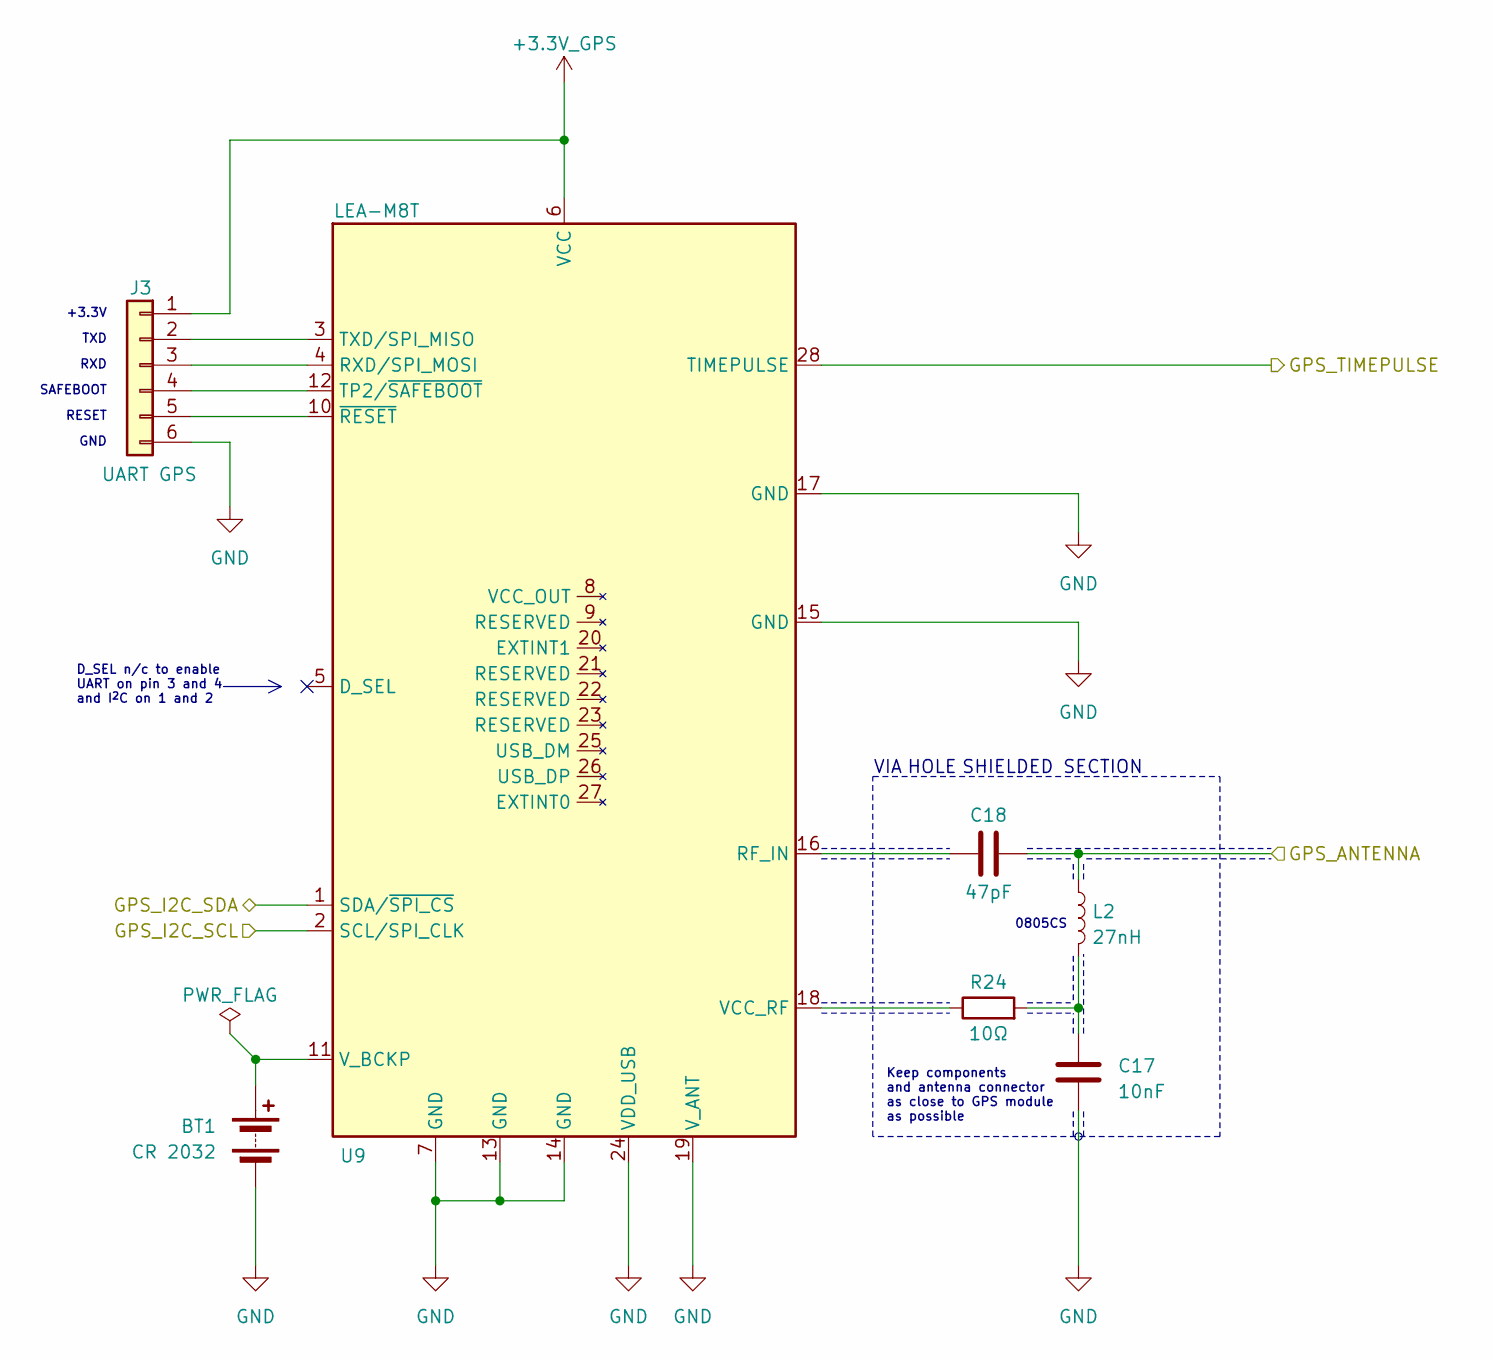
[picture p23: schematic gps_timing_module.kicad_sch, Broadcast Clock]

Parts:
BT1: CR 2032; BatteryHolder_Keystone_1058_1x2032
C17: 10nF; C_0805_2012Metric
C18: 47pF; C_0805_2012Metric
J3: UART GPS; PinHeader_1x06_P1.27mm_Vertical
L2: 27nH; L_Coilcraft_0805CS
R24: 10Ω; R_0805_2012Metric
U9: LEA-M8T; ublox_LEA

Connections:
+3.3V_GPS: J3.1, U9.6 (VCC); also elsewhere on the board
/GPS timing module/GPS_ANTENNA: C18.2, L2.1; also elsewhere on the board
/GPS timing module/GPS_TIMEPULSE: U9.28 (TIMEPULSE); also elsewhere on the board
/MCU/SCL: U9.2 (SCL/SPI_CLK); also elsewhere on the board
/MCU/SDA: U9.1 (SDA/~SPI_CS); also elsewhere on the board
GND: BT1.2 (-), C17.2, J3.6, U9.7 (GND), U9.13 (GND), U9.14 (GND), U9.15 (GND), U9.17 (GND), U9.19 (V_ANT), U9.24 (VDD_USB); also elsewhere on the board
unnamed: BT1.1 (+), U9.11 (V_BCKP)
unnamed: C17.1, L2.2, R24.2
unnamed: J3.2, U9.3 (TXD/SPI_MISO)
unnamed: J3.3, U9.4 (RXD/SPI_MOSI)
unnamed: J3.4, U9.12 (TP2/~SAFEBOOT)
unnamed: J3.5, U9.10 (~RESET)
unnamed: C18.1, U9.16 (RF_IN)
unnamed: R24.1, U9.18 (VCC_RF)

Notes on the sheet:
SAFEBOOT
0805CS
Keep components and antenna connector as close to GPS module as possible
D_SEL n/c to enable UART on pin 3 and 4 and I^{2}C on 1 and 2
RESET
VIA HOLE SHIELDED SECTION
RXD
GND
TXD
+3.3V

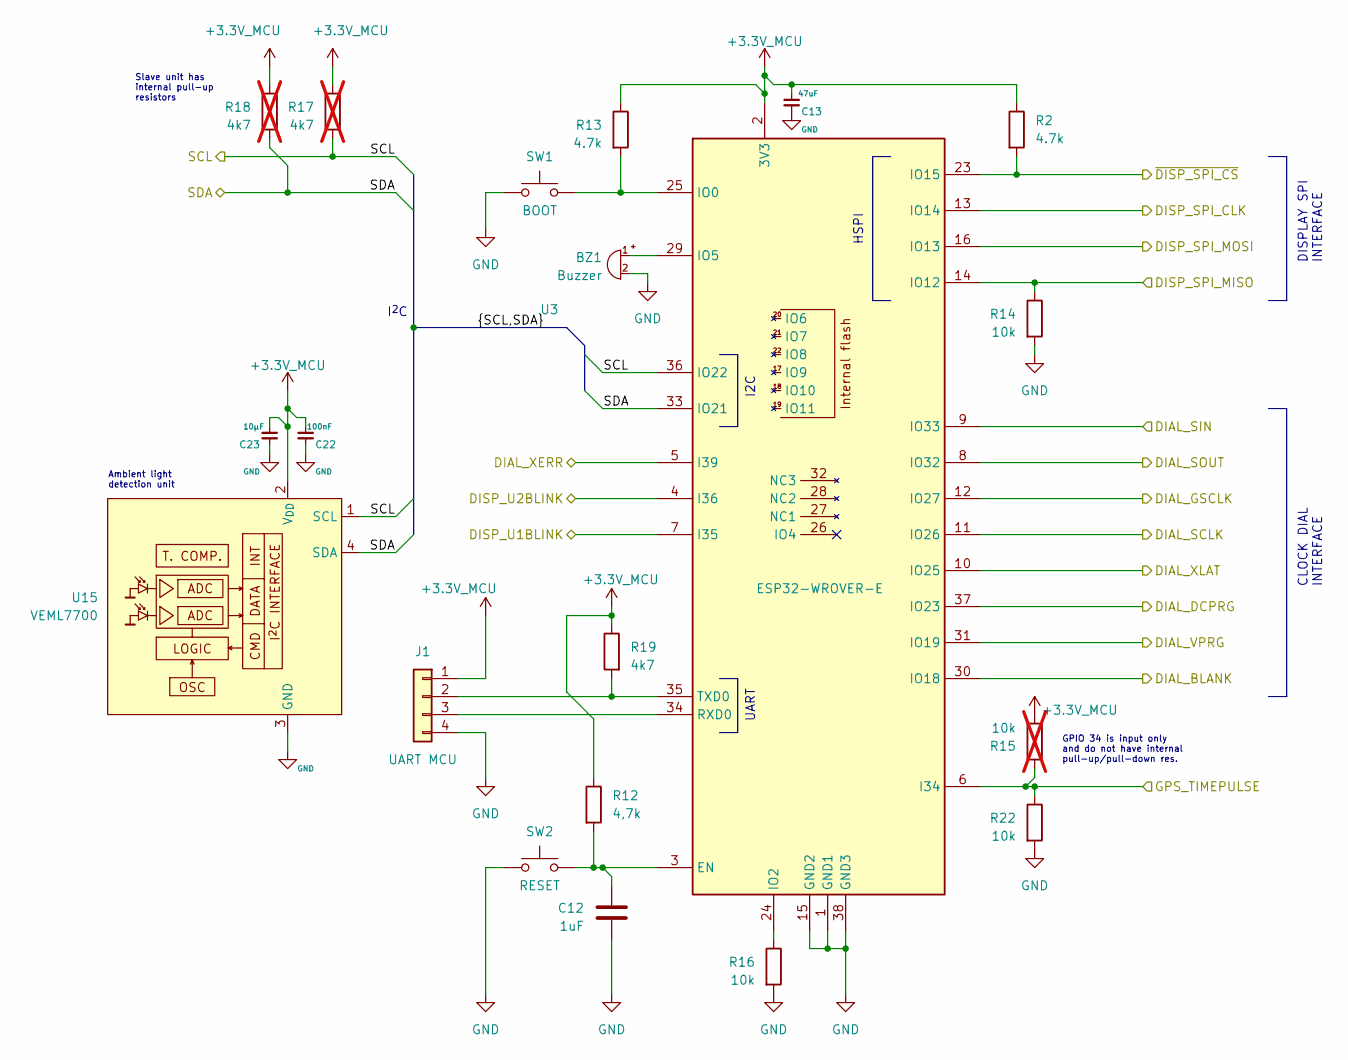
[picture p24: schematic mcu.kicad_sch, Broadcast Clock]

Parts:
BZ1: Buzzer; TP094003_Transducer_9x9mm
C12: 1uF; C_0805_2012Metric
C13: 47uF; C_0805_2012Metric
C22: 100nF; C_0805_2012Metric
C23: 10μF; C_0805_2012Metric
J1: UART MCU; Magnetic-Pogo-Female-MG0425FB_1x4_P2.54mm
R2, R13: 4.7k; R_0805_2012Metric
R12: 4,7k; R_0805_2012Metric
R14, R16, R22: 10k; R_0805_2012Metric
R15: 10k; R_0805_2012Metric; not fitted
R17, R18: 4k7; R_0805_2012Metric; not fitted
R19: 4k7; R_0805_2012Metric
SW1: BOOT; SW_SPST_TL3301_6x6mm_H4.3mm
SW2: RESET; SW_SPST_TL3301_6x6mm_H4.3mm
U3: ESP32-WROVER-E; ESP32-WROVER-B
U15: VEML7700

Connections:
+3.3V_MCU: C13.1, C22.1, C23.1, J1.1, R2.1, R12.1, R13.1, R15.2, R17.1, R18.1, R19.1, U3.2 (3V3), U15.2 (V_{DD}); also elsewhere on the board
/Clock face/DISP_U1BLINK: U3.7 (I35); also elsewhere on the board
/Clock face/DISP_U2BLINK: U3.4 (I36); also elsewhere on the board
/Clock face/LED dial/BLANK: U3.30 (IO18); also elsewhere on the board
/Clock face/LED dial/DCPRG: U3.37 (IO23); also elsewhere on the board
/Clock face/LED dial/GSCLK: U3.12 (IO27); also elsewhere on the board
/Clock face/LED dial/SCLK: U3.11 (IO26); also elsewhere on the board
/Clock face/LED dial/SIN: U3.8 (IO32); also elsewhere on the board
/Clock face/LED dial/SOUT: U3.9 (IO33); also elsewhere on the board
/Clock face/LED dial/VPRG: U3.31 (IO19); also elsewhere on the board
/Clock face/LED dial/XERR: U3.5 (I39); also elsewhere on the board
/Clock face/LED dial/XLAT: U3.10 (IO25); also elsewhere on the board
/Clock face/LED display/CLK: U3.13 (IO14); also elsewhere on the board
/Clock face/LED display/CS: R2.2, U3.23 (IO15); also elsewhere on the board
/Clock face/LED display/U1DIN: U3.16 (IO13); also elsewhere on the board
/Clock face/LED display/U2DOUT: R14.1, U3.14 (IO12); also elsewhere on the board
/GPS timing module/GPS_TIMEPULSE: R15.1, R22.1, U3.6 (I34); also elsewhere on the board
/MCU/SCL: R17.2, U3.36 (IO22), U15.1 (SCL); also elsewhere on the board
/MCU/SDA: R18.2, U3.33 (IO21), U15.4 (SDA); also elsewhere on the board
GND: BZ1.2 (+), C12.2, C13.2, C22.2, C23.2, J1.4, R14.2, R16.2, R22.2, SW1.1, SW2.1, U3.1 (GND1), U3.15 (GND2), U3.38 (GND3), U15.3 (GND); also elsewhere on the board
unnamed: BZ1.1 (-), U3.29 (IO5)
unnamed: J1.2, R19.2, U3.35 (TXD0)
unnamed: J1.3, U3.34 (RXD0)
unnamed: C12.1, R12.2, SW2.2, U3.3 (EN)
unnamed: R13.2, SW1.2, U3.25 (IO0)
unnamed: R16.1, U3.24 (IO2)

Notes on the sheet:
HSPI
I2C
CLOCK DIAL INTERFACE
Ambient light detection unit
DISPLAY SPI INTERFACE
GPIO 34 is input only and do not have internal pull-up/pull-down res.
Slave unit has internal pull-up resistors
UART
I^{2}C

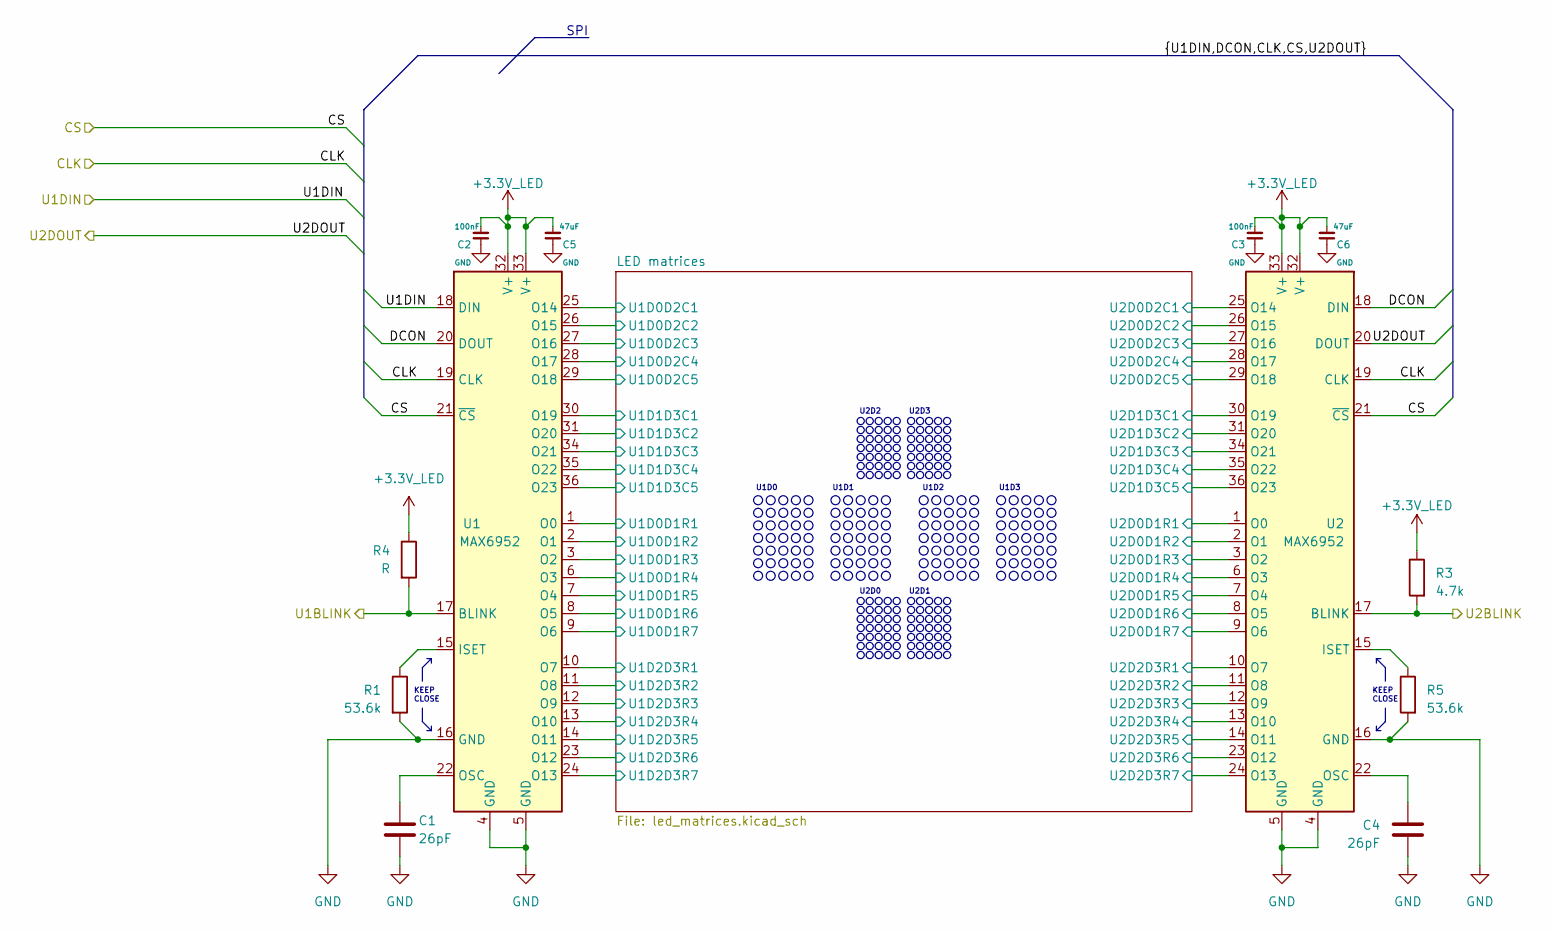
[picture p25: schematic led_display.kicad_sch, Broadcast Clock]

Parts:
C1, C4: 26pF; C_0805_2012Metric
C2, C3: 100nF; C_0805_2012Metric
C5, C6: 47uF; C_0805_2012Metric
R1, R5: 53.6k; R_0805_2012Metric
R3: 4.7k; R_0805_2012Metric
R4: R; R_0805_2012Metric
U1, U2: MAX6952; SSOP-36_7.5x12.5mm_P0.65mm

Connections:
+3.3V_LED: C2.1, C3.1, C5.1, C6.1, R3.1, R4.1, U1.32 (V+), U1.33 (V+), U2.32 (V+), U2.33 (V+); also elsewhere on the board
/Clock face/DISP_U1BLINK: R4.2, U1.17 (BLINK); also elsewhere on the board
/Clock face/DISP_U2BLINK: R3.2, U2.17 (BLINK); also elsewhere on the board
/Clock face/LED display/CLK: U1.19 (CLK), U2.19 (CLK); also elsewhere on the board
/Clock face/LED display/CS: U1.21 (~CS), U2.21 (~CS); also elsewhere on the board
/Clock face/LED display/DCON: U1.20 (DOUT), U2.18 (DIN)
/Clock face/LED display/LED matrices/U1D0D1R1: U1.1 (O0); also elsewhere on the board
/Clock face/LED display/LED matrices/U1D0D1R2: U1.2 (O1); also elsewhere on the board
/Clock face/LED display/LED matrices/U1D0D1R3: U1.3 (O2); also elsewhere on the board
/Clock face/LED display/LED matrices/U1D0D1R4: U1.6 (O3); also elsewhere on the board
/Clock face/LED display/LED matrices/U1D0D1R5: U1.7 (O4); also elsewhere on the board
/Clock face/LED display/LED matrices/U1D0D1R6: U1.8 (O5); also elsewhere on the board
/Clock face/LED display/LED matrices/U1D0D1R7: U1.9 (O6); also elsewhere on the board
/Clock face/LED display/LED matrices/U1D0D2C1: U1.25 (O14); also elsewhere on the board
/Clock face/LED display/LED matrices/U1D0D2C2: U1.26 (O15); also elsewhere on the board
/Clock face/LED display/LED matrices/U1D0D2C3: U1.27 (O16); also elsewhere on the board
/Clock face/LED display/LED matrices/U1D0D2C4: U1.28 (O17); also elsewhere on the board
/Clock face/LED display/LED matrices/U1D0D2C5: U1.29 (O18); also elsewhere on the board
/Clock face/LED display/LED matrices/U1D1D3C1: U1.30 (O19); also elsewhere on the board
/Clock face/LED display/LED matrices/U1D1D3C2: U1.31 (O20); also elsewhere on the board
/Clock face/LED display/LED matrices/U1D1D3C3: U1.34 (O21); also elsewhere on the board
/Clock face/LED display/LED matrices/U1D1D3C4: U1.35 (O22); also elsewhere on the board
/Clock face/LED display/LED matrices/U1D1D3C5: U1.36 (O23); also elsewhere on the board
/Clock face/LED display/LED matrices/U1D2D3R1: U1.10 (O7); also elsewhere on the board
/Clock face/LED display/LED matrices/U1D2D3R2: U1.11 (O8); also elsewhere on the board
/Clock face/LED display/LED matrices/U1D2D3R3: U1.12 (O9); also elsewhere on the board
/Clock face/LED display/LED matrices/U1D2D3R4: U1.13 (O10); also elsewhere on the board
/Clock face/LED display/LED matrices/U1D2D3R5: U1.14 (O11); also elsewhere on the board
/Clock face/LED display/LED matrices/U1D2D3R6: U1.23 (O12); also elsewhere on the board
/Clock face/LED display/LED matrices/U1D2D3R7: U1.24 (O13); also elsewhere on the board
/Clock face/LED display/LED matrices/U2D0D1R1: U2.1 (O0); also elsewhere on the board
/Clock face/LED display/LED matrices/U2D0D1R2: U2.2 (O1); also elsewhere on the board
/Clock face/LED display/LED matrices/U2D0D1R3: U2.3 (O2); also elsewhere on the board
/Clock face/LED display/LED matrices/U2D0D1R4: U2.6 (O3); also elsewhere on the board
/Clock face/LED display/LED matrices/U2D0D1R5: U2.7 (O4); also elsewhere on the board
/Clock face/LED display/LED matrices/U2D0D1R6: U2.8 (O5); also elsewhere on the board
/Clock face/LED display/LED matrices/U2D0D1R7: U2.9 (O6); also elsewhere on the board
/Clock face/LED display/LED matrices/U2D0D2C1: U2.25 (O14); also elsewhere on the board
/Clock face/LED display/LED matrices/U2D0D2C2: U2.26 (O15); also elsewhere on the board
/Clock face/LED display/LED matrices/U2D0D2C3: U2.27 (O16); also elsewhere on the board
/Clock face/LED display/LED matrices/U2D0D2C4: U2.28 (O17); also elsewhere on the board
/Clock face/LED display/LED matrices/U2D0D2C5: U2.29 (O18); also elsewhere on the board
/Clock face/LED display/LED matrices/U2D1D3C1: U2.30 (O19); also elsewhere on the board
/Clock face/LED display/LED matrices/U2D1D3C2: U2.31 (O20); also elsewhere on the board
/Clock face/LED display/LED matrices/U2D1D3C3: U2.34 (O21); also elsewhere on the board
/Clock face/LED display/LED matrices/U2D1D3C4: U2.35 (O22); also elsewhere on the board
/Clock face/LED display/LED matrices/U2D1D3C5: U2.36 (O23); also elsewhere on the board
/Clock face/LED display/LED matrices/U2D2D3R1: U2.10 (O7); also elsewhere on the board
/Clock face/LED display/LED matrices/U2D2D3R2: U2.11 (O8); also elsewhere on the board
/Clock face/LED display/LED matrices/U2D2D3R3: U2.12 (O9); also elsewhere on the board
/Clock face/LED display/LED matrices/U2D2D3R4: U2.13 (O10); also elsewhere on the board
/Clock face/LED display/LED matrices/U2D2D3R5: U2.14 (O11); also elsewhere on the board
/Clock face/LED display/LED matrices/U2D2D3R6: U2.23 (O12); also elsewhere on the board
/Clock face/LED display/LED matrices/U2D2D3R7: U2.24 (O13); also elsewhere on the board
/Clock face/LED display/U1DIN: U1.18 (DIN); also elsewhere on the board
/Clock face/LED display/U2DOUT: U2.20 (DOUT); also elsewhere on the board
GND: C1.1, C2.2, C3.2, C4.1, C5.2, C6.2, R1.2, R5.2, U1.4 (GND), U1.5 (GND), U1.16 (GND), U2.4 (GND), U2.5 (GND), U2.16 (GND); also elsewhere on the board
unnamed: R1.1, U1.15 (ISET)
unnamed: C1.2, U1.22 (OSC)
unnamed: R5.1, U2.15 (ISET)
unnamed: C4.2, U2.22 (OSC)

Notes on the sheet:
U1D3
KEEP CLOSE
SPI
U1D2
U2D3
U1D0
U2D2
U1D1
U2D0
U2D1

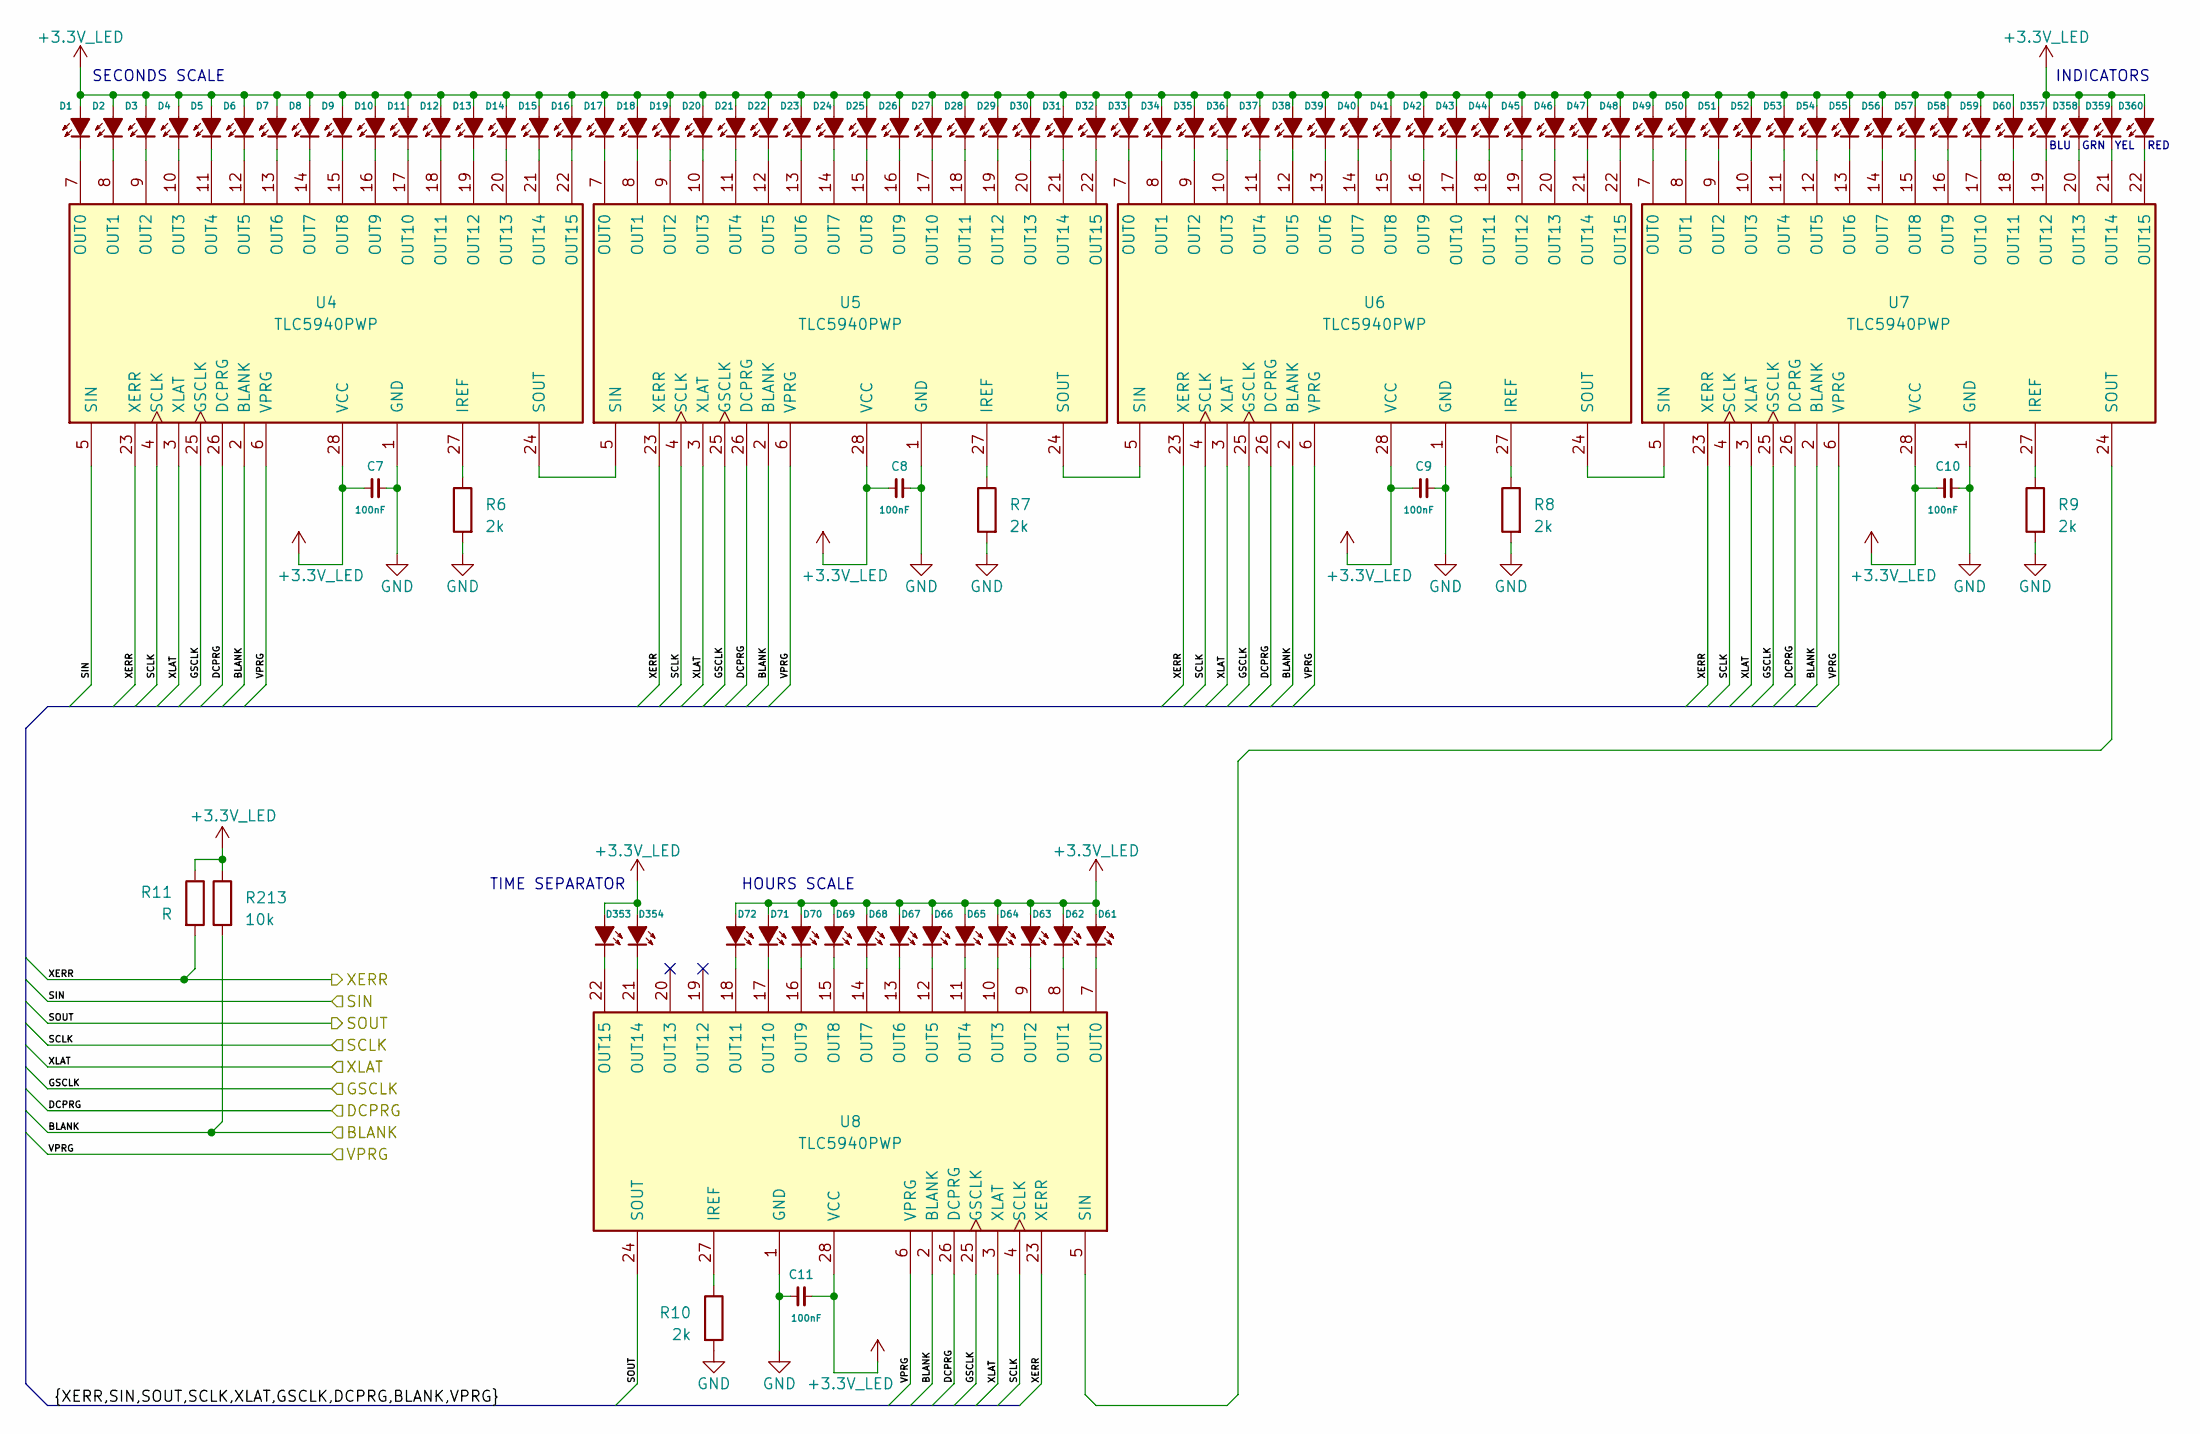
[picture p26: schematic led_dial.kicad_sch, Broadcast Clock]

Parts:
C7, C8, C9, C10, C11: 100nF; C_0805_2012Metric
D1, D2, D3, D4, D5, D6, D7, D8, D9, D10, D11, D12, D13, D14, D15, D16, D17, D18, D19, D20, D21, D22, D23, D24, D25, D26, D27, D28, D29, D30, D31, D32, D33, D34, D35, D36, D37, D38, D39, D40, D41, D42, D43, D44, D45, D46, D47, D48, D49, D50, D51, D52, D53, D54, D55, D56, D57, D58, D59, D60, D61, D62, D63, D64, D65, D66, D67, D68, D69, D70, D71, D72, D353, D354: 620nm; LED_D5.0mm_p2.54
D357: 470nm; LED_0805_2012Metric
D358: 570nm; LED_0805_2012Metric
D359: 590nm; LED_0805_2012Metric
D360: 620nm; LED_0805_2012Metric
R6, R7, R8, R9, R10: 2k; R_0805_2012Metric
R11: R; R_0805_2012Metric
R213: 10k; R_0805_2012Metric
U4, U5, U6, U7, U8: TLC5940PWP; HTSSOP-28-1EP_4.4x9.7mm_P0.65mm_EP3.4x9.5mm_Mask2.4x6.17mm_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

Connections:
+3.3V_LED: C7.1, C8.1, C9.1, C10.1, C11.1, D1.2 (A), D2.2 (A), D3.2 (A), D4.2 (A), D5.2 (A), D6.2 (A), D7.2 (A), D8.2 (A), D9.2 (A), D10.2 (A), D11.2 (A), D12.2 (A), D13.2 (A), D14.2 (A), D15.2 (A), D16.2 (A), D17.2 (A), D18.2 (A), D19.2 (A), D20.2 (A), D21.2 (A), D22.2 (A), D23.2 (A), D24.2 (A), D25.2 (A), D26.2 (A), D27.2 (A), D28.2 (A), D29.2 (A), D30.2 (A), D31.2 (A), D32.2 (A), D33.2 (A), D34.2 (A), D35.2 (A), D36.2 (A), D37.2 (A), D38.2 (A), D39.2 (A), D40.2 (A), D41.2 (A), D42.2 (A), D43.2 (A), D44.2 (A), D45.2 (A), D46.2 (A), D47.2 (A), D48.2 (A), D49.2 (A), D50.2 (A), D51.2 (A), D52.2 (A), D53.2 (A), D54.2 (A), D55.2 (A), D56.2 (A), D57.2 (A), D58.2 (A), D59.2 (A), D60.2 (A), D61.2 (A), D62.2 (A), D63.2 (A), D64.2 (A), D65.2 (A), D66.2 (A), D67.2 (A), D68.2 (A), D69.2 (A), D70.2 (A), D71.2 (A), D72.2 (A), D353.2 (A), D354.2 (A), D357.2 (A), D358.2 (A), D359.2 (A), D360.2 (A), R11.1, R213.1, U4.28 (VCC), U5.28 (VCC), U6.28 (VCC), U7.28 (VCC), U8.28 (VCC); also elsewhere on the board
/Clock face/LED dial/BLANK: R213.2, U4.2 (BLANK), U5.2 (BLANK), U6.2 (BLANK), U7.2 (BLANK), U8.2 (BLANK); also elsewhere on the board
/Clock face/LED dial/DCPRG: U4.26 (DCPRG), U5.26 (DCPRG), U6.26 (DCPRG), U7.26 (DCPRG), U8.26 (DCPRG); also elsewhere on the board
/Clock face/LED dial/GSCLK: U4.25 (GSCLK), U5.25 (GSCLK), U6.25 (GSCLK), U7.25 (GSCLK), U8.25 (GSCLK); also elsewhere on the board
/Clock face/LED dial/SCLK: U4.4 (SCLK), U5.4 (SCLK), U6.4 (SCLK), U7.4 (SCLK), U8.4 (SCLK); also elsewhere on the board
/Clock face/LED dial/SIN: U4.5 (SIN); also elsewhere on the board
/Clock face/LED dial/SOUT: U8.24 (SOUT); also elsewhere on the board
/Clock face/LED dial/VPRG: U4.6 (VPRG), U5.6 (VPRG), U6.6 (VPRG), U7.6 (VPRG), U8.6 (VPRG); also elsewhere on the board
/Clock face/LED dial/XERR: R11.2, U4.23 (XERR), U5.23 (XERR), U6.23 (XERR), U7.23 (XERR), U8.23 (XERR); also elsewhere on the board
/Clock face/LED dial/XLAT: U4.3 (XLAT), U5.3 (XLAT), U6.3 (XLAT), U7.3 (XLAT), U8.3 (XLAT); also elsewhere on the board
GND: C7.2, C8.2, C9.2, C10.2, C11.2, R6.2, R7.2, R8.2, R9.2, R10.2, U4.1 (GND), U5.1 (GND), U6.1 (GND), U7.1 (GND), U8.1 (GND); also elsewhere on the board
unnamed: D1.1 (K), U4.7 (OUT0)
unnamed: D2.1 (K), U4.8 (OUT1)
unnamed: D3.1 (K), U4.9 (OUT2)
unnamed: D4.1 (K), U4.10 (OUT3)
unnamed: D5.1 (K), U4.11 (OUT4)
unnamed: D6.1 (K), U4.12 (OUT5)
unnamed: D7.1 (K), U4.13 (OUT6)
unnamed: D8.1 (K), U4.14 (OUT7)
unnamed: D9.1 (K), U4.15 (OUT8)
unnamed: D10.1 (K), U4.16 (OUT9)
unnamed: D11.1 (K), U4.17 (OUT10)
unnamed: D12.1 (K), U4.18 (OUT11)
unnamed: D13.1 (K), U4.19 (OUT12)
unnamed: D14.1 (K), U4.20 (OUT13)
unnamed: D15.1 (K), U4.21 (OUT14)
unnamed: D16.1 (K), U4.22 (OUT15)
unnamed: D17.1 (K), U5.7 (OUT0)
unnamed: D18.1 (K), U5.8 (OUT1)
unnamed: D19.1 (K), U5.9 (OUT2)
unnamed: D20.1 (K), U5.10 (OUT3)
unnamed: D21.1 (K), U5.11 (OUT4)
unnamed: D22.1 (K), U5.12 (OUT5)
unnamed: D23.1 (K), U5.13 (OUT6)
unnamed: D24.1 (K), U5.14 (OUT7)
unnamed: D25.1 (K), U5.15 (OUT8)
unnamed: D26.1 (K), U5.16 (OUT9)
unnamed: D27.1 (K), U5.17 (OUT10)
unnamed: D28.1 (K), U5.18 (OUT11)
unnamed: D29.1 (K), U5.19 (OUT12)
unnamed: D30.1 (K), U5.20 (OUT13)
unnamed: D31.1 (K), U5.21 (OUT14)
unnamed: D32.1 (K), U5.22 (OUT15)
unnamed: D33.1 (K), U6.7 (OUT0)
unnamed: D34.1 (K), U6.8 (OUT1)
unnamed: D35.1 (K), U6.9 (OUT2)
unnamed: D36.1 (K), U6.10 (OUT3)
unnamed: D37.1 (K), U6.11 (OUT4)
unnamed: D38.1 (K), U6.12 (OUT5)
unnamed: D39.1 (K), U6.13 (OUT6)
unnamed: D40.1 (K), U6.14 (OUT7)
unnamed: D41.1 (K), U6.15 (OUT8)
unnamed: D42.1 (K), U6.16 (OUT9)
unnamed: D43.1 (K), U6.17 (OUT10)
unnamed: D44.1 (K), U6.18 (OUT11)
unnamed: D45.1 (K), U6.19 (OUT12)
unnamed: D46.1 (K), U6.20 (OUT13)
unnamed: D47.1 (K), U6.21 (OUT14)
unnamed: D48.1 (K), U6.22 (OUT15)
unnamed: D49.1 (K), U7.7 (OUT0)
unnamed: D50.1 (K), U7.8 (OUT1)
unnamed: D51.1 (K), U7.9 (OUT2)
unnamed: D52.1 (K), U7.10 (OUT3)
unnamed: D53.1 (K), U7.11 (OUT4)
unnamed: D54.1 (K), U7.12 (OUT5)
unnamed: D55.1 (K), U7.13 (OUT6)
unnamed: D56.1 (K), U7.14 (OUT7)
unnamed: D57.1 (K), U7.15 (OUT8)
unnamed: D58.1 (K), U7.16 (OUT9)
unnamed: D59.1 (K), U7.17 (OUT10)
unnamed: D60.1 (K), U7.18 (OUT11)
unnamed: D61.1 (K), U8.7 (OUT0)
unnamed: D62.1 (K), U8.8 (OUT1)
unnamed: D63.1 (K), U8.9 (OUT2)
unnamed: D64.1 (K), U8.10 (OUT3)
unnamed: D65.1 (K), U8.11 (OUT4)
unnamed: D66.1 (K), U8.12 (OUT5)
unnamed: D67.1 (K), U8.13 (OUT6)
unnamed: D68.1 (K), U8.14 (OUT7)
unnamed: D69.1 (K), U8.15 (OUT8)
unnamed: D70.1 (K), U8.16 (OUT9)
unnamed: D71.1 (K), U8.17 (OUT10)
unnamed: D72.1 (K), U8.18 (OUT11)
unnamed: D353.1 (K), U8.22 (OUT15)
unnamed: D354.1 (K), U8.21 (OUT14)
unnamed: D357.1 (K), U7.19 (OUT12)
unnamed: D358.1 (K), U7.20 (OUT13)
unnamed: D359.1 (K), U7.21 (OUT14)
unnamed: D360.1 (K), U7.22 (OUT15)
unnamed: R6.1, U4.27 (IREF)
unnamed: U4.24 (SOUT), U5.5 (SIN)
unnamed: R7.1, U5.27 (IREF)
unnamed: U5.24 (SOUT), U6.5 (SIN)
unnamed: R8.1, U6.27 (IREF)
unnamed: U6.24 (SOUT), U7.5 (SIN)
unnamed: R9.1, U7.27 (IREF)
unnamed: U7.24 (SOUT), U8.5 (SIN)
unnamed: R10.1, U8.27 (IREF)

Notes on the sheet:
BLU
YEL
HOURS SCALE
SECONDS SCALE
RED
INDICATORS
TIME SEPARATOR
GRN

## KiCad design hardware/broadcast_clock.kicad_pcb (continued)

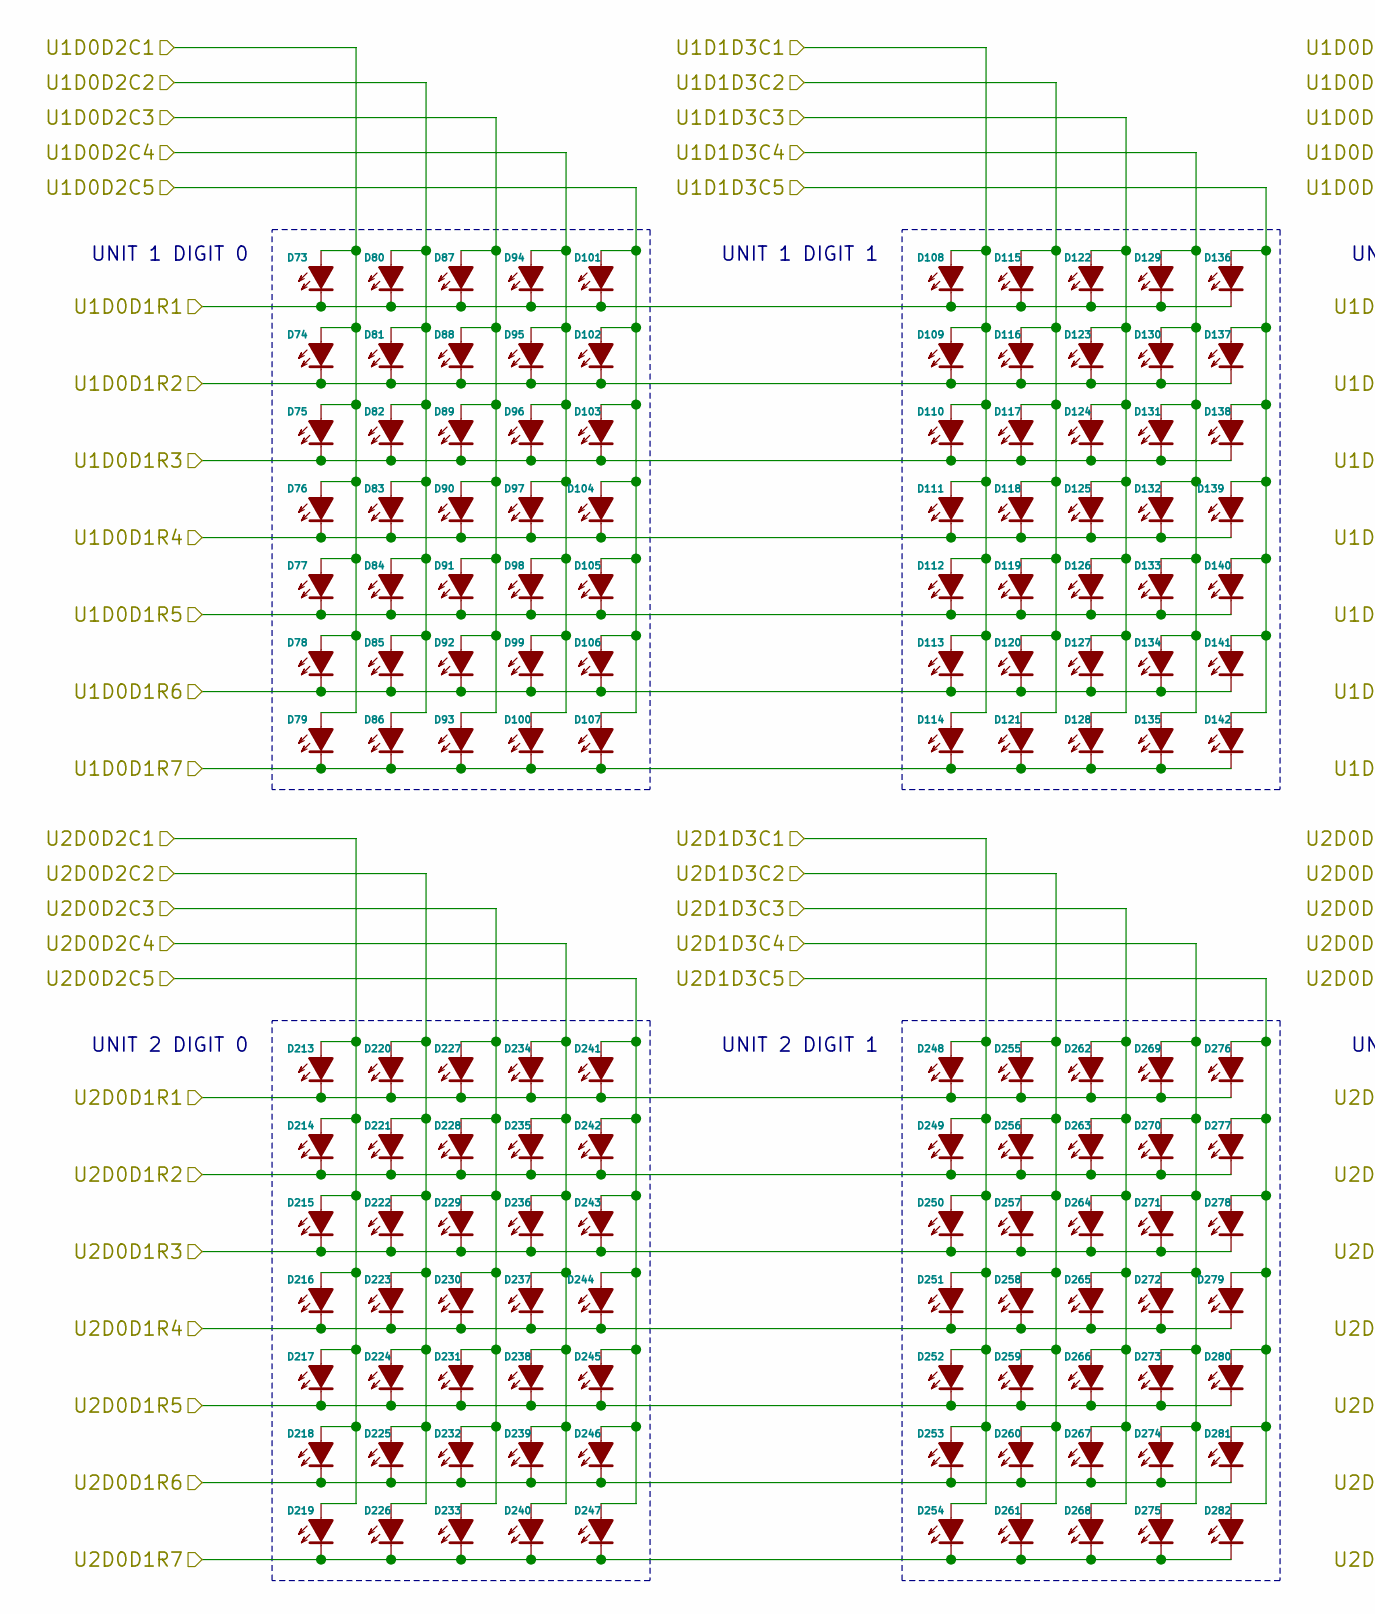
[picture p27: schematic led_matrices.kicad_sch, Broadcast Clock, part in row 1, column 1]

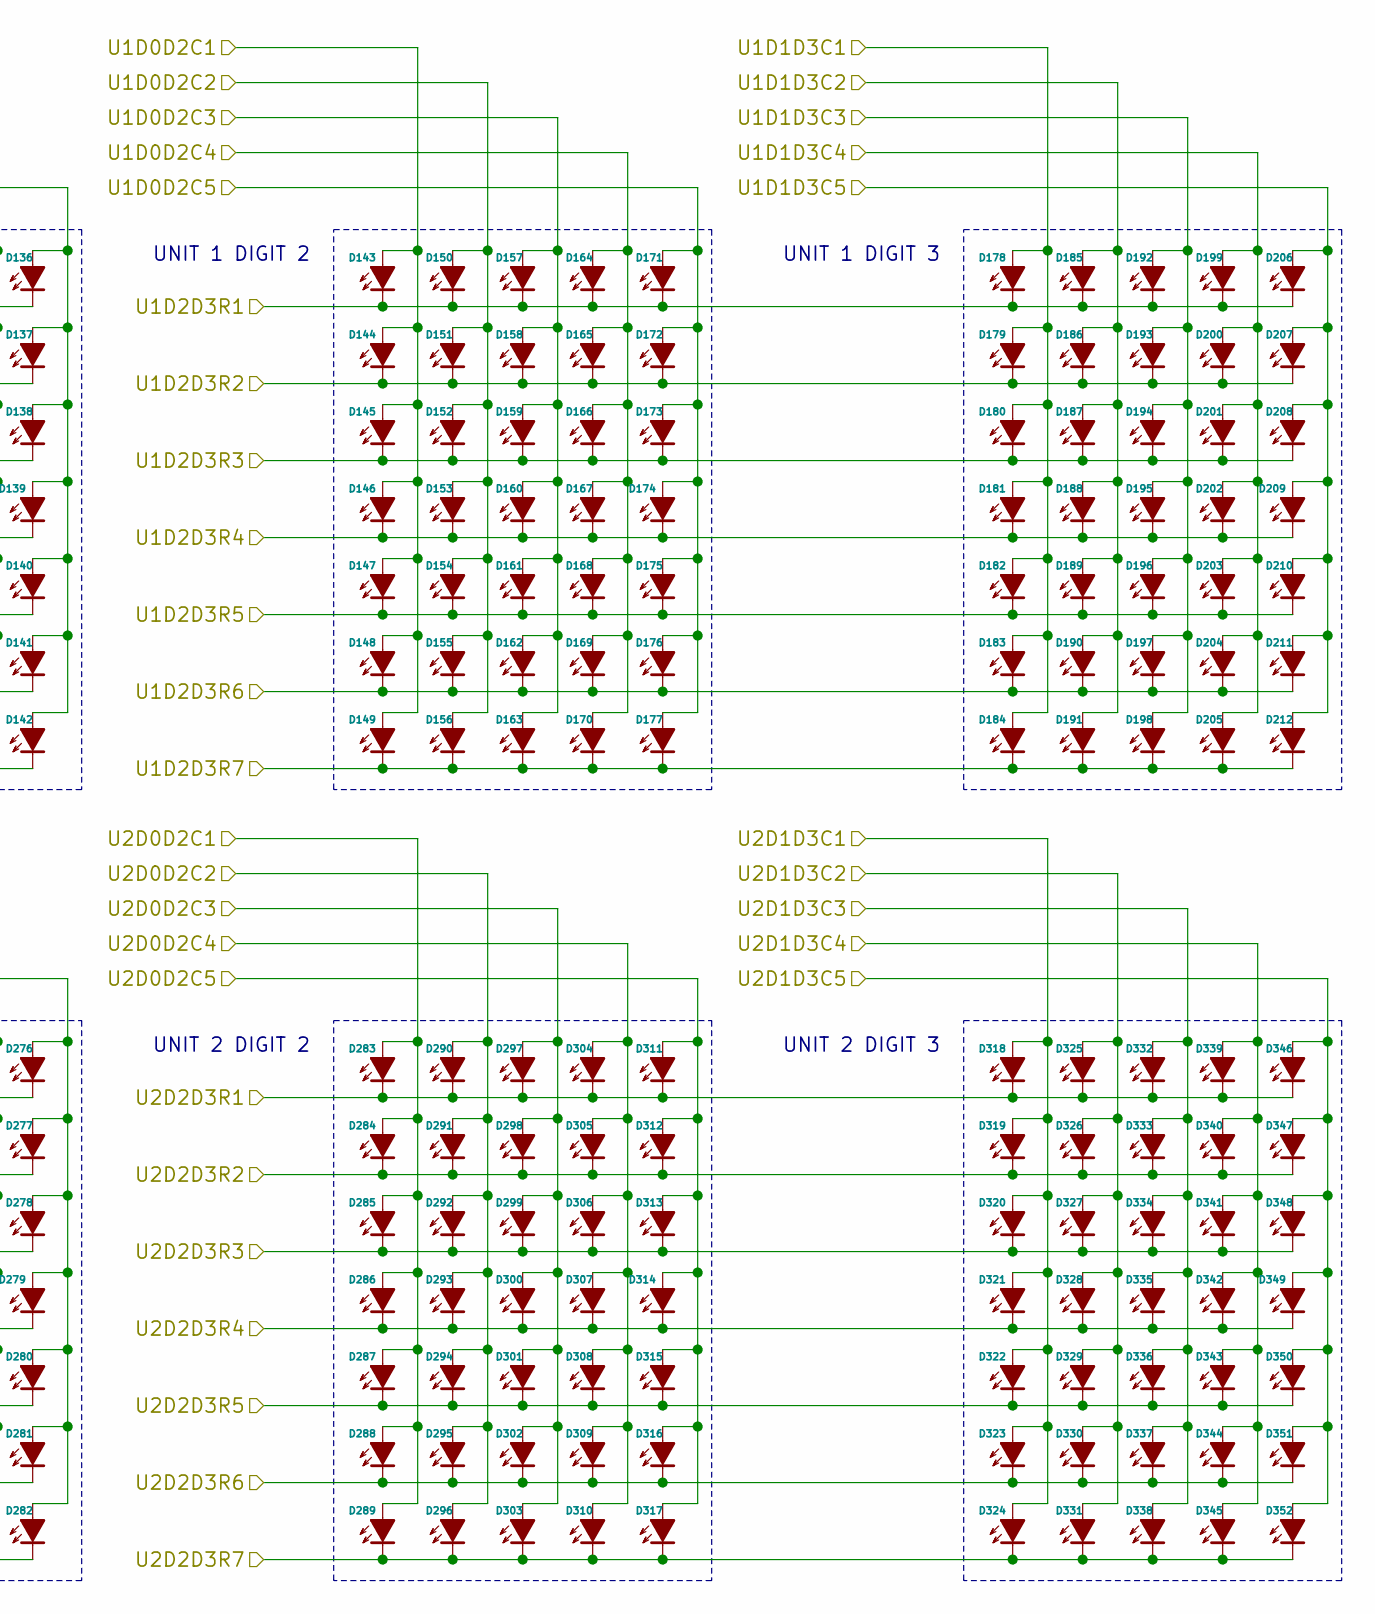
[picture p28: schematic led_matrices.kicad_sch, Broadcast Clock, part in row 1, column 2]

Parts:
D73, D74, D75, D76, D77, D78, D79, D80, D81, D82, D83, D84, D85, D86, D87, D88, D89, D90, D91, D92, D93, D94, D95, D96, D97, D98, D99, D100, D101, D102, D103, D104, D105, D106, D107, D108, D109, D110, D111, D112, D113, D114, D115, D116, D117, D118, D119, D120, D121, D122, D123, D124, D125, D126, D127, D128, D129, D130, D131, D132, D133, D134, D135, D136, D137, D138, D139, D140, D141, D142, D143, D144, D145, D146, D147, D148, D149, D150, D151, D152, D153, D154, D155, D156, D157, D158, D159, D160, D161, D162, D163, D164, D165, D166, D167, D168, D169, D170, D171, D172, D173, D174, D175, D176, D177, D178, D179, D180, D181, D182, D183, D184, D185, D186, D187, D188, D189, D190, D191, D192, D193, D194, D195, D196, D197, D198, D199, D200, D201, D202, D203, D204, D205, D206, D207, D208, D209, D210, D211, D212: 620nm; LED_D5.0mm_p2.54
D213, D214, D215, D216, D217, D218, D219, D220, D221, D222, D223, D224, D225, D226, D227, D228, D229, D230, D231, D232, D233, D234, D235, D236, D237, D238, D239, D240, D241, D242, D243, D244, D245, D246, D247, D248, D249, D250, D251, D252, D253, D254, D255, D256, D257, D258, D259, D260, D261, D262, D263, D264, D265, D266, D267, D268, D269, D270, D271, D272, D273, D274, D275, D276, D277, D278, D279, D280, D281, D282, D283, D284, D285, D286, D287, D288, D289, D290, D291, D292, D293, D294, D295, D296, D297, D298, D299, D300, D301, D302, D303, D304, D305, D306, D307, D308, D309, D310, D311, D312, D313, D314, D315, D316, D317, D318, D319, D320, D321, D322, D323, D324, D325, D326, D327, D328, D329, D330, D331, D332, D333, D334, D335, D336, D337, D338, D339, D340, D341, D342, D343, D344, D345, D346, D347, D348, D349, D350, D351, D352: 620nm; LED_D3.0mm_p2.28

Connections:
/Clock face/LED display/LED matrices/U1D0D1R1: D73.1 (K), D80.1 (K), D87.1 (K), D94.1 (K), D101.1 (K), D108.1 (K), D115.1 (K), D122.1 (K), D129.1 (K), D136.1 (K); also elsewhere on the board
/Clock face/LED display/LED matrices/U1D0D1R2: D74.1 (K), D81.1 (K), D88.1 (K), D95.1 (K), D102.1 (K), D109.1 (K), D116.1 (K), D123.1 (K), D130.1 (K), D137.1 (K); also elsewhere on the board
/Clock face/LED display/LED matrices/U1D0D1R3: D75.1 (K), D82.1 (K), D89.1 (K), D96.1 (K), D103.1 (K), D110.1 (K), D117.1 (K), D124.1 (K), D131.1 (K), D138.1 (K); also elsewhere on the board
/Clock face/LED display/LED matrices/U1D0D1R4: D76.1 (K), D83.1 (K), D90.1 (K), D97.1 (K), D104.1 (K), D111.1 (K), D118.1 (K), D125.1 (K), D132.1 (K), D139.1 (K); also elsewhere on the board
/Clock face/LED display/LED matrices/U1D0D1R5: D77.1 (K), D84.1 (K), D91.1 (K), D98.1 (K), D105.1 (K), D112.1 (K), D119.1 (K), D126.1 (K), D133.1 (K), D140.1 (K); also elsewhere on the board
/Clock face/LED display/LED matrices/U1D0D1R6: D78.1 (K), D85.1 (K), D92.1 (K), D99.1 (K), D106.1 (K), D113.1 (K), D120.1 (K), D127.1 (K), D134.1 (K), D141.1 (K); also elsewhere on the board
/Clock face/LED display/LED matrices/U1D0D1R7: D79.1 (K), D86.1 (K), D93.1 (K), D100.1 (K), D107.1 (K), D114.1 (K), D121.1 (K), D128.1 (K), D135.1 (K), D142.1 (K); also elsewhere on the board
/Clock face/LED display/LED matrices/U1D0D2C1: D73.2 (A), D74.2 (A), D75.2 (A), D76.2 (A), D77.2 (A), D78.2 (A), D79.2 (A), D143.2 (A), D144.2 (A), D145.2 (A), D146.2 (A), D147.2 (A), D148.2 (A), D149.2 (A); also elsewhere on the board
/Clock face/LED display/LED matrices/U1D0D2C2: D80.2 (A), D81.2 (A), D82.2 (A), D83.2 (A), D84.2 (A), D85.2 (A), D86.2 (A), D150.2 (A), D151.2 (A), D152.2 (A), D153.2 (A), D154.2 (A), D155.2 (A), D156.2 (A); also elsewhere on the board
/Clock face/LED display/LED matrices/U1D0D2C3: D87.2 (A), D88.2 (A), D89.2 (A), D90.2 (A), D91.2 (A), D92.2 (A), D93.2 (A), D157.2 (A), D158.2 (A), D159.2 (A), D160.2 (A), D161.2 (A), D162.2 (A), D163.2 (A); also elsewhere on the board
/Clock face/LED display/LED matrices/U1D0D2C4: D94.2 (A), D95.2 (A), D96.2 (A), D97.2 (A), D98.2 (A), D99.2 (A), D100.2 (A), D164.2 (A), D165.2 (A), D166.2 (A), D167.2 (A), D168.2 (A), D169.2 (A), D170.2 (A); also elsewhere on the board
/Clock face/LED display/LED matrices/U1D0D2C5: D101.2 (A), D102.2 (A), D103.2 (A), D104.2 (A), D105.2 (A), D106.2 (A), D107.2 (A), D171.2 (A), D172.2 (A), D173.2 (A), D174.2 (A), D175.2 (A), D176.2 (A), D177.2 (A); also elsewhere on the board
/Clock face/LED display/LED matrices/U1D1D3C1: D108.2 (A), D109.2 (A), D110.2 (A), D111.2 (A), D112.2 (A), D113.2 (A), D114.2 (A), D178.2 (A), D179.2 (A), D180.2 (A), D181.2 (A), D182.2 (A), D183.2 (A), D184.2 (A); also elsewhere on the board
/Clock face/LED display/LED matrices/U1D1D3C2: D115.2 (A), D116.2 (A), D117.2 (A), D118.2 (A), D119.2 (A), D120.2 (A), D121.2 (A), D185.2 (A), D186.2 (A), D187.2 (A), D188.2 (A), D189.2 (A), D190.2 (A), D191.2 (A); also elsewhere on the board
/Clock face/LED display/LED matrices/U1D1D3C3: D122.2 (A), D123.2 (A), D124.2 (A), D125.2 (A), D126.2 (A), D127.2 (A), D128.2 (A), D192.2 (A), D193.2 (A), D194.2 (A), D195.2 (A), D196.2 (A), D197.2 (A), D198.2 (A); also elsewhere on the board
/Clock face/LED display/LED matrices/U1D1D3C4: D129.2 (A), D130.2 (A), D131.2 (A), D132.2 (A), D133.2 (A), D134.2 (A), D135.2 (A), D199.2 (A), D200.2 (A), D201.2 (A), D202.2 (A), D203.2 (A), D204.2 (A), D205.2 (A); also elsewhere on the board
/Clock face/LED display/LED matrices/U1D1D3C5: D136.2 (A), D137.2 (A), D138.2 (A), D139.2 (A), D140.2 (A), D141.2 (A), D142.2 (A), D206.2 (A), D207.2 (A), D208.2 (A), D209.2 (A), D210.2 (A), D211.2 (A), D212.2 (A); also elsewhere on the board
/Clock face/LED display/LED matrices/U1D2D3R1: D143.1 (K), D150.1 (K), D157.1 (K), D164.1 (K), D171.1 (K), D178.1 (K), D185.1 (K), D192.1 (K), D199.1 (K), D206.1 (K); also elsewhere on the board
/Clock face/LED display/LED matrices/U1D2D3R2: D144.1 (K), D151.1 (K), D158.1 (K), D165.1 (K), D172.1 (K), D179.1 (K), D186.1 (K), D193.1 (K), D200.1 (K), D207.1 (K); also elsewhere on the board
/Clock face/LED display/LED matrices/U1D2D3R3: D145.1 (K), D152.1 (K), D159.1 (K), D166.1 (K), D173.1 (K), D180.1 (K), D187.1 (K), D194.1 (K), D201.1 (K), D208.1 (K); also elsewhere on the board
/Clock face/LED display/LED matrices/U1D2D3R4: D146.1 (K), D153.1 (K), D160.1 (K), D167.1 (K), D174.1 (K), D181.1 (K), D188.1 (K), D195.1 (K), D202.1 (K), D209.1 (K); also elsewhere on the board
/Clock face/LED display/LED matrices/U1D2D3R5: D147.1 (K), D154.1 (K), D161.1 (K), D168.1 (K), D175.1 (K), D182.1 (K), D189.1 (K), D196.1 (K), D203.1 (K), D210.1 (K); also elsewhere on the board
/Clock face/LED display/LED matrices/U1D2D3R6: D148.1 (K), D155.1 (K), D162.1 (K), D169.1 (K), D176.1 (K), D183.1 (K), D190.1 (K), D197.1 (K), D204.1 (K), D211.1 (K); also elsewhere on the board
/Clock face/LED display/LED matrices/U1D2D3R7: D149.1 (K), D156.1 (K), D163.1 (K), D170.1 (K), D177.1 (K), D184.1 (K), D191.1 (K), D198.1 (K), D205.1 (K), D212.1 (K); also elsewhere on the board
/Clock face/LED display/LED matrices/U2D0D1R1: D213.1 (K), D220.1 (K), D227.1 (K), D234.1 (K), D241.1 (K), D248.1 (K), D255.1 (K), D262.1 (K), D269.1 (K), D276.1 (K); also elsewhere on the board
/Clock face/LED display/LED matrices/U2D0D1R2: D214.1 (K), D221.1 (K), D228.1 (K), D235.1 (K), D242.1 (K), D249.1 (K), D256.1 (K), D263.1 (K), D270.1 (K), D277.1 (K); also elsewhere on the board
/Clock face/LED display/LED matrices/U2D0D1R3: D215.1 (K), D222.1 (K), D229.1 (K), D236.1 (K), D243.1 (K), D250.1 (K), D257.1 (K), D264.1 (K), D271.1 (K), D278.1 (K); also elsewhere on the board
/Clock face/LED display/LED matrices/U2D0D1R4: D216.1 (K), D223.1 (K), D230.1 (K), D237.1 (K), D244.1 (K), D251.1 (K), D258.1 (K), D265.1 (K), D272.1 (K), D279.1 (K); also elsewhere on the board
/Clock face/LED display/LED matrices/U2D0D1R5: D217.1 (K), D224.1 (K), D231.1 (K), D238.1 (K), D245.1 (K), D252.1 (K), D259.1 (K), D266.1 (K), D273.1 (K), D280.1 (K); also elsewhere on the board
/Clock face/LED display/LED matrices/U2D0D1R6: D218.1 (K), D225.1 (K), D232.1 (K), D239.1 (K), D246.1 (K), D253.1 (K), D260.1 (K), D267.1 (K), D274.1 (K), D281.1 (K); also elsewhere on the board
/Clock face/LED display/LED matrices/U2D0D1R7: D219.1 (K), D226.1 (K), D233.1 (K), D240.1 (K), D247.1 (K), D254.1 (K), D261.1 (K), D268.1 (K), D275.1 (K), D282.1 (K); also elsewhere on the board
/Clock face/LED display/LED matrices/U2D0D2C1: D213.2 (A), D214.2 (A), D215.2 (A), D216.2 (A), D217.2 (A), D218.2 (A), D219.2 (A), D283.2 (A), D284.2 (A), D285.2 (A), D286.2 (A), D287.2 (A), D288.2 (A), D289.2 (A); also elsewhere on the board
/Clock face/LED display/LED matrices/U2D0D2C2: D220.2 (A), D221.2 (A), D222.2 (A), D223.2 (A), D224.2 (A), D225.2 (A), D226.2 (A), D290.2 (A), D291.2 (A), D292.2 (A), D293.2 (A), D294.2 (A), D295.2 (A), D296.2 (A); also elsewhere on the board
/Clock face/LED display/LED matrices/U2D0D2C3: D227.2 (A), D228.2 (A), D229.2 (A), D230.2 (A), D231.2 (A), D232.2 (A), D233.2 (A), D297.2 (A), D298.2 (A), D299.2 (A), D300.2 (A), D301.2 (A), D302.2 (A), D303.2 (A); also elsewhere on the board
/Clock face/LED display/LED matrices/U2D0D2C4: D234.2 (A), D235.2 (A), D236.2 (A), D237.2 (A), D238.2 (A), D239.2 (A), D240.2 (A), D304.2 (A), D305.2 (A), D306.2 (A), D307.2 (A), D308.2 (A), D309.2 (A), D310.2 (A); also elsewhere on the board
/Clock face/LED display/LED matrices/U2D0D2C5: D241.2 (A), D242.2 (A), D243.2 (A), D244.2 (A), D245.2 (A), D246.2 (A), D247.2 (A), D311.2 (A), D312.2 (A), D313.2 (A), D314.2 (A), D315.2 (A), D316.2 (A), D317.2 (A); also elsewhere on the board
/Clock face/LED display/LED matrices/U2D1D3C1: D248.2 (A), D249.2 (A), D250.2 (A), D251.2 (A), D252.2 (A), D253.2 (A), D254.2 (A), D318.2 (A), D319.2 (A), D320.2 (A), D321.2 (A), D322.2 (A), D323.2 (A), D324.2 (A); also elsewhere on the board
/Clock face/LED display/LED matrices/U2D1D3C2: D255.2 (A), D256.2 (A), D257.2 (A), D258.2 (A), D259.2 (A), D260.2 (A), D261.2 (A), D325.2 (A), D326.2 (A), D327.2 (A), D328.2 (A), D329.2 (A), D330.2 (A), D331.2 (A); also elsewhere on the board
/Clock face/LED display/LED matrices/U2D1D3C3: D262.2 (A), D263.2 (A), D264.2 (A), D265.2 (A), D266.2 (A), D267.2 (A), D268.2 (A), D332.2 (A), D333.2 (A), D334.2 (A), D335.2 (A), D336.2 (A), D337.2 (A), D338.2 (A); also elsewhere on the board
/Clock face/LED display/LED matrices/U2D1D3C4: D269.2 (A), D270.2 (A), D271.2 (A), D272.2 (A), D273.2 (A), D274.2 (A), D275.2 (A), D339.2 (A), D340.2 (A), D341.2 (A), D342.2 (A), D343.2 (A), D344.2 (A), D345.2 (A); also elsewhere on the board
/Clock face/LED display/LED matrices/U2D1D3C5: D276.2 (A), D277.2 (A), D278.2 (A), D279.2 (A), D280.2 (A), D281.2 (A), D282.2 (A), D346.2 (A), D347.2 (A), D348.2 (A), D349.2 (A), D350.2 (A), D351.2 (A), D352.2 (A); also elsewhere on the board
/Clock face/LED display/LED matrices/U2D2D3R1: D283.1 (K), D290.1 (K), D297.1 (K), D304.1 (K), D311.1 (K), D318.1 (K), D325.1 (K), D332.1 (K), D339.1 (K), D346.1 (K); also elsewhere on the board
/Clock face/LED display/LED matrices/U2D2D3R2: D284.1 (K), D291.1 (K), D298.1 (K), D305.1 (K), D312.1 (K), D319.1 (K), D326.1 (K), D333.1 (K), D340.1 (K), D347.1 (K); also elsewhere on the board
/Clock face/LED display/LED matrices/U2D2D3R3: D285.1 (K), D292.1 (K), D299.1 (K), D306.1 (K), D313.1 (K), D320.1 (K), D327.1 (K), D334.1 (K), D341.1 (K), D348.1 (K); also elsewhere on the board
/Clock face/LED display/LED matrices/U2D2D3R4: D286.1 (K), D293.1 (K), D300.1 (K), D307.1 (K), D314.1 (K), D321.1 (K), D328.1 (K), D335.1 (K), D342.1 (K), D349.1 (K); also elsewhere on the board
/Clock face/LED display/LED matrices/U2D2D3R5: D287.1 (K), D294.1 (K), D301.1 (K), D308.1 (K), D315.1 (K), D322.1 (K), D329.1 (K), D336.1 (K), D343.1 (K), D350.1 (K); also elsewhere on the board
/Clock face/LED display/LED matrices/U2D2D3R6: D288.1 (K), D295.1 (K), D302.1 (K), D309.1 (K), D316.1 (K), D323.1 (K), D330.1 (K), D337.1 (K), D344.1 (K), D351.1 (K); also elsewhere on the board
/Clock face/LED display/LED matrices/U2D2D3R7: D289.1 (K), D296.1 (K), D303.1 (K), D310.1 (K), D317.1 (K), D324.1 (K), D331.1 (K), D338.1 (K), D345.1 (K), D352.1 (K); also elsewhere on the board

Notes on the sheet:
UNIT 2 DIGIT 2
UNIT 2 DIGIT 0
UNIT 1 DIGIT 0
UNIT 2 DIGIT 1
UNIT 2 DIGIT 3
UNIT 1 DIGIT 1
UNIT 1 DIGIT 3
UNIT 1 DIGIT 2

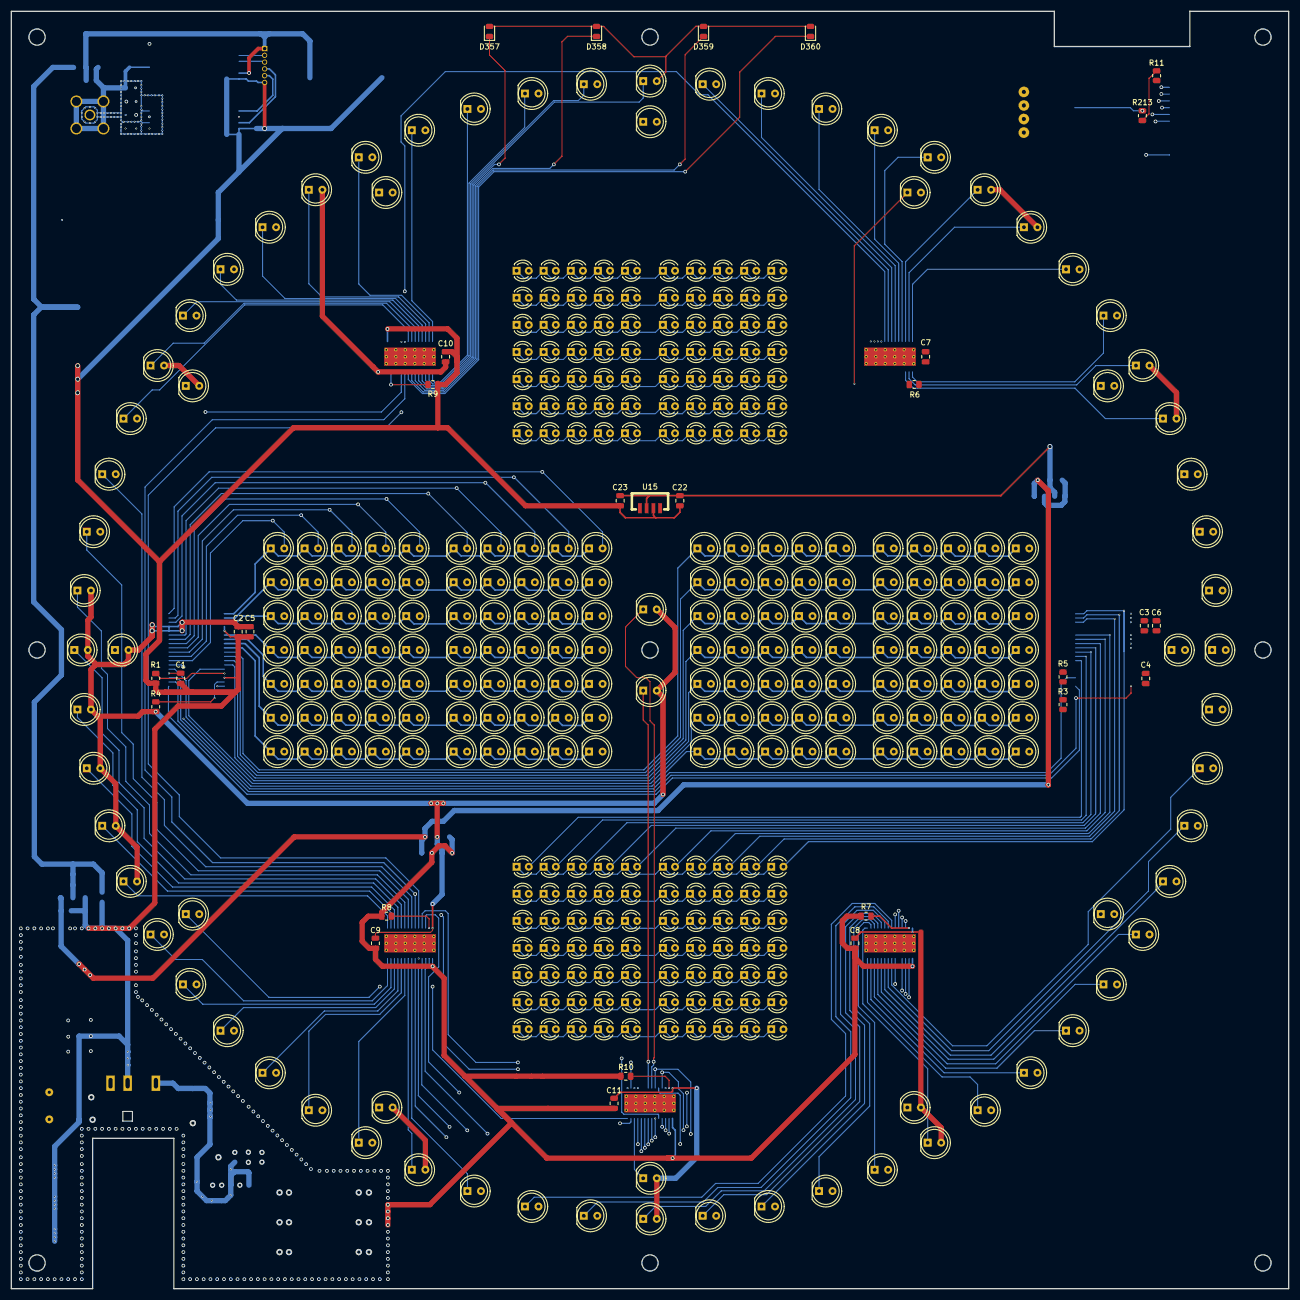
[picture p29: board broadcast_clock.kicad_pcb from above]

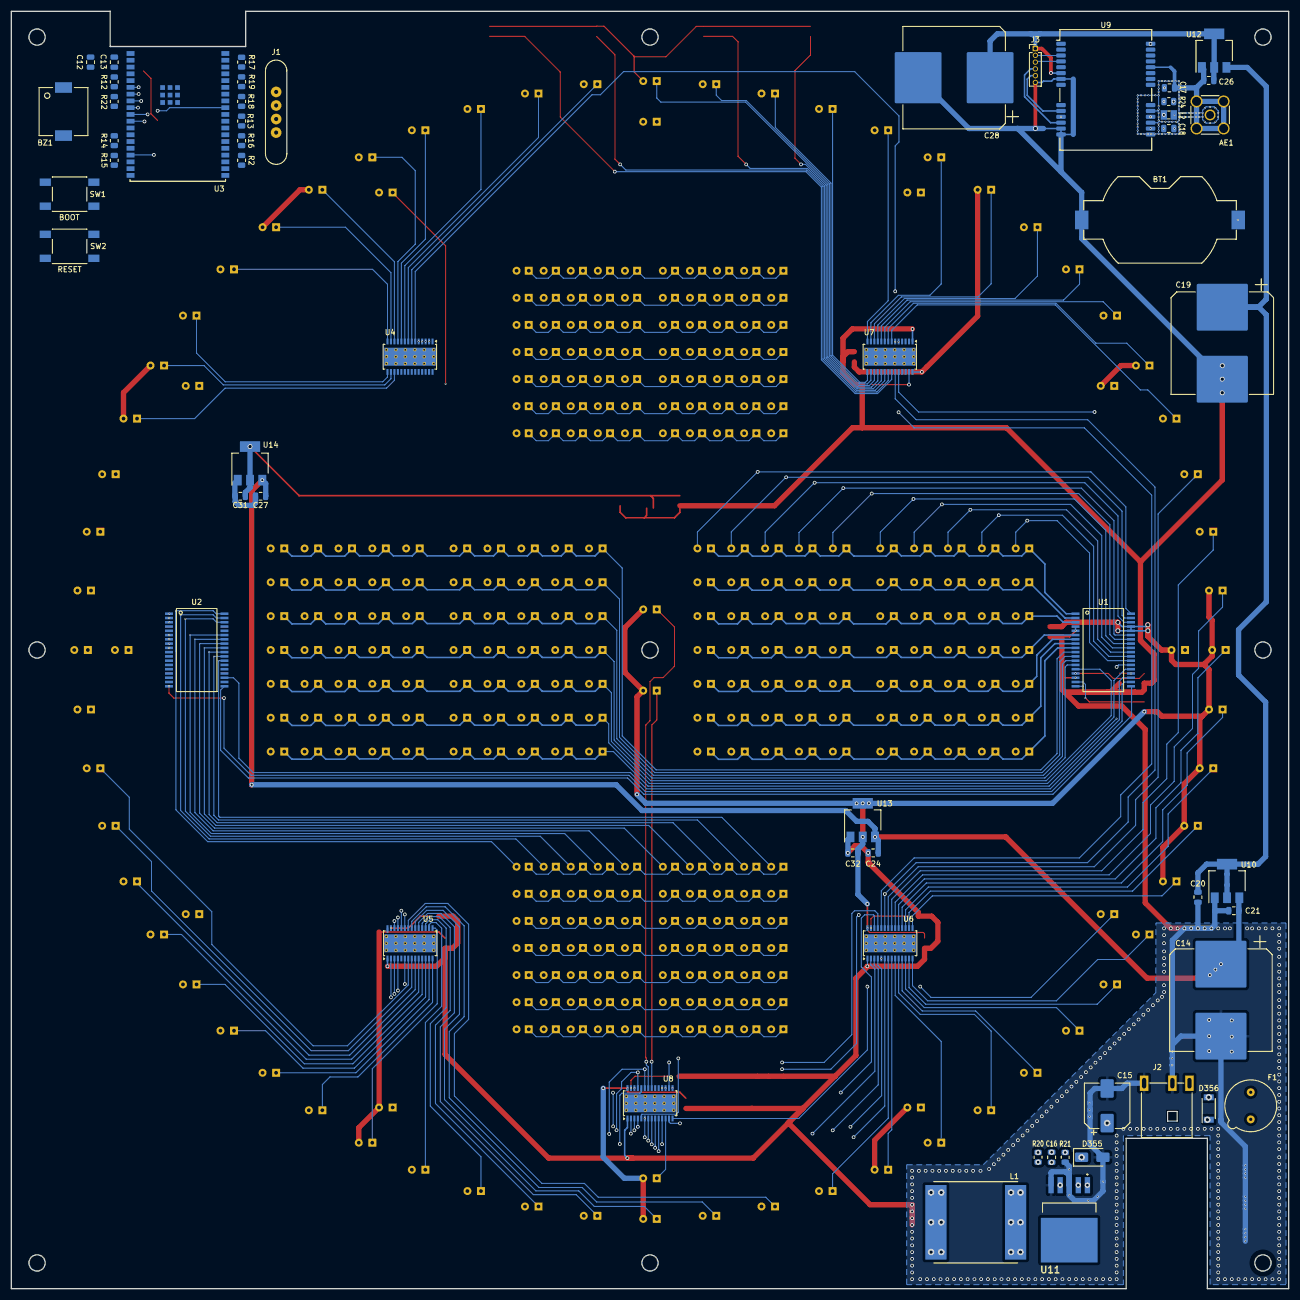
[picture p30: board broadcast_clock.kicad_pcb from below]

Board: 4 copper layers, 239.5 x 239.5 mm, 439 parts (56 on the bottom side), 184 nets.

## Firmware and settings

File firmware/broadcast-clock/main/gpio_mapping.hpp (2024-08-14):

#ifndef GPIO_MAPPING_HPP
#define GPIO_MAPPING_HPP

#include <driver/gpio.h>

// Piezo transducer GPIO
#define PIEZO_TRANSDUCER GPIO_NUM_5

// Dial GPIO mapping
#define DIAL_SIN    GPIO_NUM_33
#define DIAL_SOUT   GPIO_NUM_32
#define DIAL_GSCLK  GPIO_NUM_27
#define DIAL_SCLK   GPIO_NUM_26
#define DIAL_XLAT   GPIO_NUM_25
#define DIAL_DCPRG  GPIO_NUM_23
#define DIAL_VPRG   GPIO_NUM_19
#define DIAL_BLANK  GPIO_NUM_18
#define DIAL_XERR   GPIO_NUM_39

// Dot matrix GPIO mapping
#define DISP_SPI_CS GPIO_NUM_15
#define DISP_SPI_CLK GPIO_NUM_14
#define DISP_SPI_MOSI GPIO_NUM_13
#define DISP_SPI_MISO GPIO_NUM_12

// I2C GPIO mapping
#define I2C_SCL GPIO_NUM_22
#define I2C_SDA GPIO_NUM_21

// LEA M8T GPIO mapping
#define LEA_M8T_TIMEPULSE GPIO_NUM_34

#endif // GPIO_MAPPING_HPP

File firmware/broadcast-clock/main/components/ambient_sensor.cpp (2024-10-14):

#include "ambient_sensor.hpp"
#include "../gpio_mapping.hpp"
#include <freertos/FreeRTOS.h>
#include <freertos/task.h>
#include <memory.h>
#include <driver/i2c.h>
#include <esp_log.h>

#define I2C_MASTER_WRITE 0
#define I2C_MASTER_READ 1

using namespace espena;

const char *broadcast_clock::ambient_sensor::m_component_name = "ambient_sensor";

broadcast_clock::ambient_sensor::
ambient_sensor() {
    
}

broadcast_clock::ambient_sensor::
~ambient_sensor() {

}

void broadcast_clock::ambient_sensor::
init() {
  ESP_LOGI( m_component_name, "Initializing" );
  init_sensor();
}

void broadcast_clock::ambient_sensor::
init_sensor() {

  uint8_t cmd_config[ ] = { 0x00, 0b00001000, 0b11000000 };
  i2c_cmd_handle_t cmd = i2c_cmd_link_create();
  i2c_master_start( cmd );
  i2c_master_write_byte( cmd, ( m_i2c_address << 1 ) | I2C_MASTER_WRITE, true );
  i2c_master_write( cmd, cmd_config, sizeof( cmd_config ), true );
  i2c_master_stop( cmd );
  esp_err_t res = i2c_master_cmd_begin( I2C_NUM_0, cmd, 1000 );
  i2c_cmd_link_delete( cmd );

}

uint16_t broadcast_clock::ambient_sensor::
read() {
  uint8_t cmd_read_als[ ] = { 0x04 };
  uint8_t buf_lux_val[ ] = { 0x00, 0x00 };
  uint16_t lux = 0;

  esp_err_t res = i2c_master_write_read_device( I2C_NUM_0,
                                                m_i2c_address,
                                                cmd_read_als,
                                                sizeof( cmd_read_als ),
                                                buf_lux_val,
                                                sizeof( buf_lux_val ),
                                                -1 );

  if( res == ESP_OK ) {
    lux = ( buf_lux_val[ 0 ] << 8 ) | buf_lux_val[ 1 ];
  }

  return lux;
}

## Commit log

2024-05-11 Rename KiCAD folder
    [broadcast_clock.kicad_pcb, broadcast_clock.kicad_sch, clock_face.kicad_sch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]
2024-05-12 Add 3D rendering from KiCAD
2024-05-12 Assign footprints
    [broadcast_clock.kicad_sch, gps_timing_module.kicad_sch, led_dial.kicad_sch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]
2024-05-12 Insert vertical spacing
2024-05-26 Starting PCB routing process
    [broadcast_clock.kicad_pcb, broadcast_clock.kicad_sch, clock_face.kicad_sch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]
2024-05-28 Routing in progress
    [broadcast_clock.kicad_pcb, gps_timing_module.kicad_sch, led_dial.kicad_sch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]
2024-06-01 Adding thermal zones
    [broadcast_clock.kicad_pcb, broadcast_clock.kicad_sch, clock_face.kicad_sch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]
2024-06-05 Add graphics
    [back_plate.dxf, front_panel.dxf, logo.dxf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]
2024-06-05 Open thermal pad for buck converter
    Former-commit-id: e6c8dc76280dd95d3ab8586baa877e8ee88db5e2
    [broadcast_clock-B_Cu.gbr, broadcast_clock-B_Mask.gbr, broadcast_clock-B_Paste.gbr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]
2024-07-05 Prototype, starting on firmware
    Former-commit-id: 3c22e4f94bda4a4eed472ac1ff762e7709731c05
    Former-commit-id: afce4fecf5b4961621dea2f3a514203675ae8e80
    [broadcast_clock-B_Cu.gbr, broadcast_clock-B_Mask.gbr, broadcast_clock-B_Paste.gbr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]
2024-07-05 Remove large 3D files
    Former-commit-id: fe92c8cc630f44c9ad765bc8c56d44807531d97d
    Former-commit-id: 5229d8a8b0247ce2fddd517664bf60847fdd22d5
    Former-commit-id: 9a5f131d8090c7a510589660489c359ea0d1adff
    [complete_assembly-circuit_board.obj]
2024-07-06 Firmware for LED drivers, dial and matrix
    Former-commit-id: d06b369f7cd35a3c902f0729a1b8d2d05c7c9555
2024-07-08 Adding inner frame moutning holes
    Former-commit-id: 4f5b56c85d6e0a8106ced6b64ecd934ffc52be82
    [clock_panels.dxf]
2024-07-08 Adding driver for ambient light sensor
    Former-commit-id: 2bce65af87f10816012582e2dad0f4f90b30a819
2024-07-10 Fix display lags, implement brightness adjustment
    Former-commit-id: 36ce102e70e0466296d428186528265a70c2a012
    [dial.cpp, dotmatrix.cpp]
2024-07-11 Fix bug causing unintentionally entering config mode
    [dial.cpp, dotmatrix.cpp]
2024-07-13 Fixed serial communication with the 5940 chips
    [dial.cpp, gpio_mapping.hpp]
2024-07-13 Fix HTML config page
    [ambient_sensor.cpp, dial.cpp]
2024-07-14 Stop debug printing of current light level
2024-07-14 Ignore KiCAD temporary files
2024-07-15 Implement auto/fixed brightness control
    [dial.cpp, dotmatrix.cpp]
2024-07-16 Fix bugs in configurator and remember current tab on reload
    [application.cpp]
2024-07-16 Fix bug in clock mode probing
    [dotmatrix.cpp]
2024-07-16 Adjust hole sizes
    [back_plate.dxf]
2024-07-16 Update mounting holes, create toolpath for milling
    [back_plate.dxf, clock_panels.dxf]
2024-07-16 Fix bug in displaying meridiem (AM/PM)
    [dotmatrix.cpp]
2024-07-18 Slightly adjust buttons position
2024-07-19 Start implement countdown timer
2024-07-19 Add GUI for countdown timer
2024-07-19 Adding info about timers
2024-07-21 Adding beeper for alarms, IP display at boot and do away with flickering
    [mcu.kicad_sch]
2024-07-21 Fix NTP status indicators
    [dial.cpp]
2024-07-23 Refactor dial interface to TLC5940, remove PWM and timers, use loops while keeping WDT in leash
2024-07-23 Rename 'ambient sensor' timer name, it is now doing several things
2024-07-23 Update back panel drawing, add measurements
    [back_plate.dxf]
2024-07-23 Fix bug in clock refresh cycle
    [dial.cpp]
2024-07-26 Update schematics
2024-08-03 Add bill of material
    [bill_of_material_broadcast_clock.xls]
2024-08-03 Display pcb related layers only
    [clock_panels.dxf]
2024-08-03 Change fuse from 2A to 250 mA
    [power_supply.kicad_sch]
2024-08-03 Change capacitor value from 26 to 27 pF which is a standard value
    [led_display.kicad_sch]
2024-08-04 Move bill of material into hardware directory
    [bill_of_material_broadcast_clock.xls]
2024-08-06 Remove R19, pull-up disturbs serial communication
    [mcu.kicad_sch]
2024-08-08 Minor design updates
    [led_dial.kicad_sch, led_display.kicad_sch, mcu.kicad_sch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]
2024-08-14 Add display test mode
    [mcu.kicad_sch]
2024-09-21 Downgrade to previous version of the i2c driver
2024-09-25 Set i2c clock speed back to 400K
2024-09-28 Fix UI for starting and stopping survey-in
    [lea_m8t.cpp, lea_m8t.hpp]
2024-10-01 Expand to 16 MB flash memory
    [partitions.csv]
2024-10-05 Moved memory allocation to SPI RAM for lea_m8t messages
2024-10-12 Fix timepulse absence detection
    [lea_m8t.cpp]
2024-10-12 Red LED is now blinking on lower accuracy
2024-10-14 Re-implement ambient light sensor
2024-10-19 Limit reboot animation to the launch buttons
2024-10-19 Make reboot button selectors more narrow.
2024-10-20 Improve GUI, disable cancel button in STA mode
2024-10-20 Show cancel button on APSTA mode
2024-10-28 Correctly handle clocks with no GNSS
    [application.cpp, lea_m8t.cpp, lea_m8t.hpp]
2024-12-27 Bugfix: Implement mutex to protect HTTP port from concurrent access
    [lea_m8t.cpp]
2025-03-06 Updated project to work with KiCAD version 9
    [broadcast_clock.kicad_sch, clock_face.kicad_sch, gps_timing_module.kicad_sch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]
2025-03-06 Update project to KiCAD v9
